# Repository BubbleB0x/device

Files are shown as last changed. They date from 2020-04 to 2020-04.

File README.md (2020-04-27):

# BUBBLEBOX DEVICE #

## INDICE ##
_________________________________________________________________________________________
1. Descrizione
2. Moduli e dispositivi utilizzati
3. inizializzazione
4. Directory Tree
5. Firmware Schede
6. Consumi, costi e caratteristiche
8. Connessione moduli(implementazione device)
9. Funzionamento

______________________________________________________________________________________________

## Descrizione ##
________________________________________________________________________________________________

Sistema di rilevamento di prossimità per prevenire e rilevare l’espansione del COVID-19 (e altre forme virali), attraverso l’uso di un device e di un App (non essenziale, ma che fornisce funzionalità aggiuntive) smartphone e web. Oltre all’analisi dei dati, questo progetto, effettua soprattutto una raccolta puntuale, completa, precisa e organizzata, con dati pronti per essere analizzati, infatti, il device effettuerà un vero proprio Edge Computing, in modo da gestire lui stesso i dati e presentarli, attraverso più canali comunicativi (Bluetooth smartphone o WiFi), al sistema server. Il nome BubbleBox proviene proprio dall’idea di una bolla virtuale attorno ad ogni individuo che, se violata, da quella di un altro, ottiene ID di quest’ultimo (in modo sicuro e anonimo) e invia la segnalazione ad un server online, dopo essere stato elaborato, per analisi e verifiche future. Se un individuo dovesse essere positivo al COVID-19 allora verranno allertate e controllate tutte le persone con cui è entrato in contatto senza ambiguità alcuna. A differenza di alcuni sistemi di tracciamento già presenti, il nostro fornisce un servizio funzionante in ogni luogo e offline, perché la raccolta avviene prima in locale poi, quando disponibile, viene inoltrata online.

---> [REPORT](https://github.com/BubbleB0x/device/blob/master/doc/report/Relazione_Bubblebox(RignanesePolenta).pdf)

----------------------------------------------------------------------------------------------------

## Moduli e dispositivi utilizzati (singolo device) ##
___________________________________________________________________________________________________

* ESP32
* RF-NANO
* Display LED
* Modulo RTC
* Modulo scheda SD

-----------------------------------------------------------------------------------------------------

## Inizializzazione ##

____________________________________________________________________________________________________

* Installazione [IDE Arduino](https://www.arduino.cc/en/Main/Software)
* Installazione CORE ESP32:
	- Arduino IDE > `File` > `Impostazioni` > `Schede` > URL Schede > `https://dl.espressif.com/dl/package_esp32_index.json`
	- Arduino IDE > `Strumenti` > `Scheda` > `ESP32 Dev Model`
	- Arduino IDE > `Strumenti` > `Partition Scheme `> `NO OTA (2MB APP/2MB SPIFFS)`
* Installazione Librerie:
	* Installazione [librerie ESP32](https://github.com/espressif/arduino-esp32)
		- Il link contiene tantissime librery per il device ESP32, tuttavia, nella repo è presente solamente la libvreria utile che viene utilizzata (per facilitare l'inizializzazione)
		- Arduino IDE > Sketch > #Include libreria > Aggiungi libreria da file .ZIP
	* Installazione [librerie NRF24L01](https://github.com/maniacbug/RF24)
		- Arduino IDE > Sketch > #Include libreria > Aggiungi libreria da file .ZIP
	
	----------> TUTTE LE LIBRERIE CHE SERVONO SONO INSERITE NELLA DIRECTORY `/Library`
	
* Possibili problematiche: 
	- è possibile che quando si connette l'ESP32 alla porta USB del PC non venga letta
	- aprire `Gestione Dispoitivi`
	- vedere se tra i device presenti c'è qualche problema o warning
	- andare sul problema e cliccare col tasto destro > `Aggiorna Driver`
	- il problema dovrebbe essere rsolto riavviando la IDE di Arduino

_____________________________________________________________________________________________________
	
## Directory Tree ##
_____________________________________________________________________________________________________

* *img*: Logo e altre immagini
* *firmware*:
	* *ESP32*:
		* *Device_SempreAttivi*: Device con ESP32 sempre in funzione (grande spreco di batteria)
		* *Device_Sleep&Wake*: Device con ESP32 in DeepSleep (grande risparmio di batteria)
	* *RFNANO*: Modulo RFNano con NRF24L01 per scandagliare l'area alla ricerca dei device vicini (consuma meno del modulo ESP32 e viene usato solo per scandagliare l'area) funziona a supporto dell'ESP32
* *doc* : 
	* *business_plan*
	* *report*
	* *altri documenti*
* *scheme*: Schemi sul funzionamento del device
* *Library*: Contiene tutte le librerie che servono ai componenti per poter funzionare
* *circuits*

_______________________________________________________________________________________________________

## Firmware Schede ##
________________________________________________________________________________________________________
* Clonare la repo
	- `git clone https://orteip94@bitbucket.org/bbteam_/bubblebox-device.git`
* Installare gli sketch sulle schede:
	- RFNANO:
		- Aprire Arduino IDE
		- Inserire la scheda RFNAno
		- Arduino IDE > Strumenti > Scheda > Arduino Nano > `Processore:ATMega328P`
		- Selezionare Porta
		- Installare sketch contenuto nella directory `Sketch Device/RFNano`
	- ESP32:
		- Aprire Arduino IDE
		- Inserire la scheda ESP32
		- Arduino IDE > Strumenti > Scheda > `ESP32 Dev Model`
		- Arduino IDE > Strumenti > Partition Scheme > `NO OTA (2MB APP/2MB SPIFFS)`
		- Selezionare Porta
		- Installare sketch contenuto nella directory `firmware/ESP32/Device_Sleep&Wake`
	
_______________________________________________________________________________________________________

## Consumi costi e caratteristiche componenti ##
________________________________________________________________________________________________________

| *Componente* | *Consumo Wake* |  *Consumo DeepSleep*  | *Prezzo* | *Caratteristiche* |
| ---|---|---|---|---|
| ESP32 | 50mA |  0,05 mA | 9€ | Wi-Fi & BLE |
| RF-NANO  | 19mA | 0,05 mA | 8€ | Radio Wave |
|Display OLED| 30mA | 0,9 mA | 8€ | Display 0.96" |
| Lettore SD |  30mA | 5 mA | 5€ | Data Storage  |
| Modulo RTC |0,8mA | 0,08 mA | 6€ | Orologio e data |
|  | *Totale*  |  *Totale* |  *Totale*  |  |
| - | 130 mA |  6,08 mA | 36€ | - |

## Connessioni Dispositivi(Implementazione Device) ##
_________________________________________________________________________________________________________

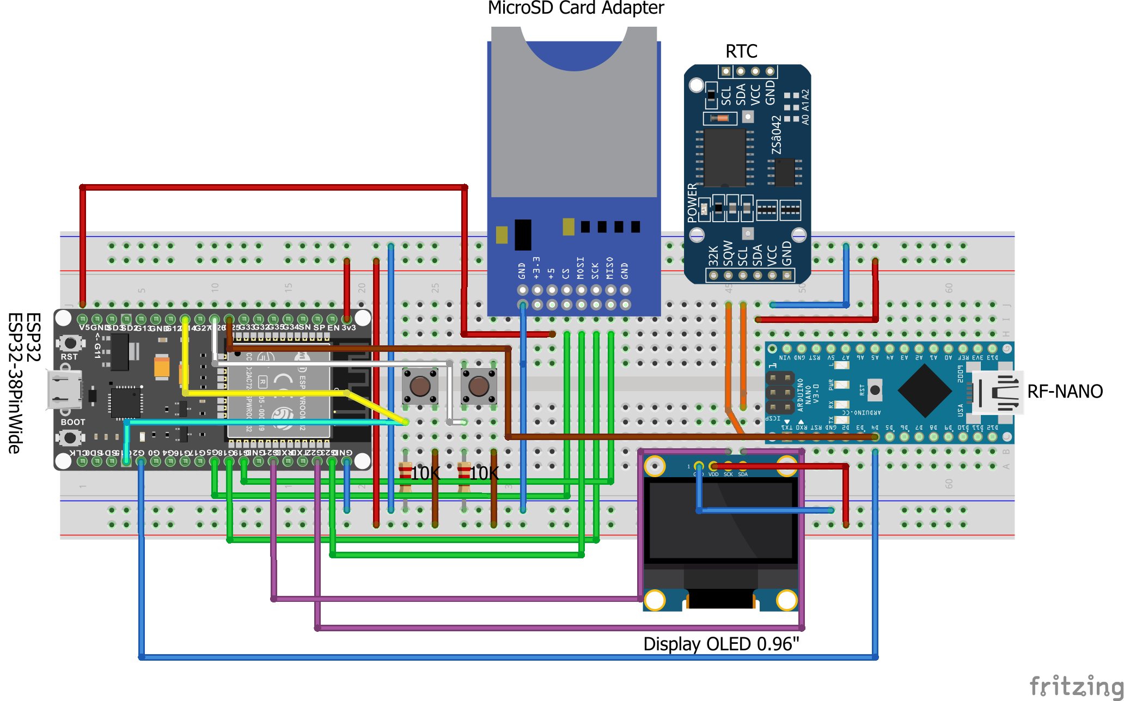
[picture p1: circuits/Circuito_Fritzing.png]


| *ESP32* | *RFNANO* |  *RTC*  | *DISPLAY* | *SD CARD* | *Bottone 1* | *Bottone 2*|
| ---|---|---|---|---|---|---|
| GPIO 25 | D4 |  - | -  | - |  - |  -  |
| GPIO 21 | - |  SCL | SCL  | - |  -  |  - |
| GPIO 22 | - |  SDA  | SDA  | - | -  |  - |
| GPIO 19 | - |  - | -  | MISO  | -  |  - |
| GPIO 23 | - |  - | -  | MOSI | -  |  - |
| GPIO 18 | - |  - | -  | SCK | -  |  - |
| GPIO 5 | - |  - | -  | CS | -  |  - |
| GPIO 14 | - |  - | -  | - | OK(Cambio Display)  |  - |
| GPIO 26 | - |  - | -  | - | -  |  OK(Sel. Opzione Display) |
| GPIO 2 | D4(Wake)  |  - | -  | - | -  |  - |
| GPIO 15 | - |  - | -  | - | OK(WAKE)  |  - |
| 3V | - |  VCC  | VCC  | - | VCC  |  VCC |
| 5V | - |  -  | -  | VCC | -  |  - |
| GND | - |  GND  | GND  | GND | GND  |  GND |

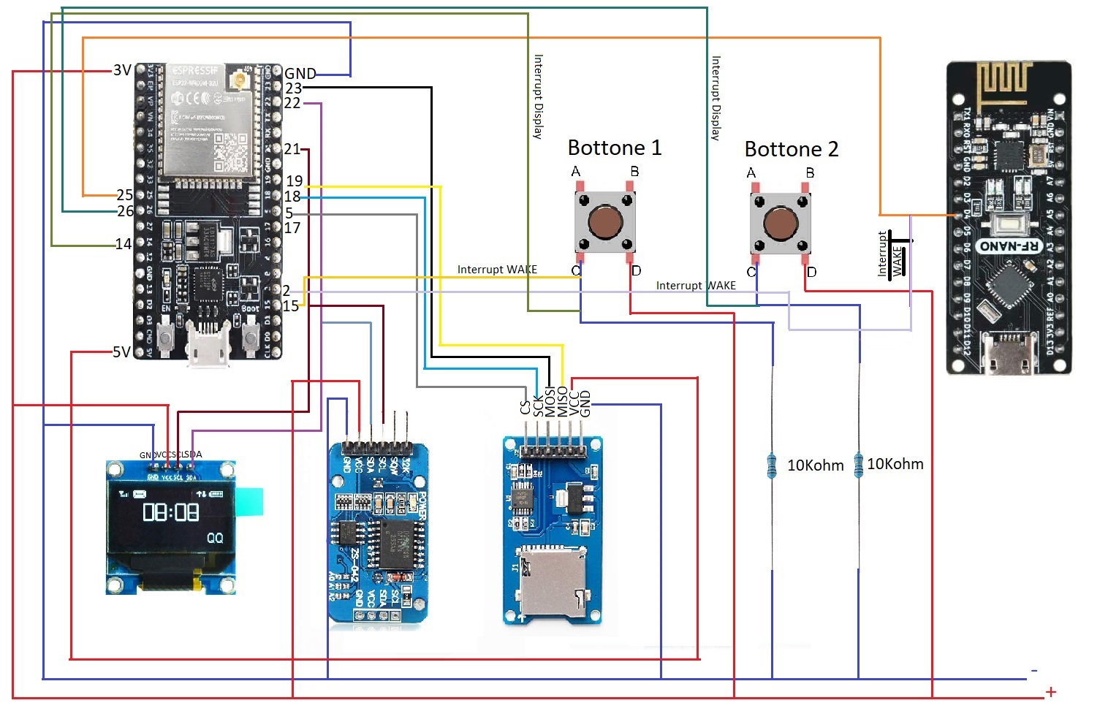
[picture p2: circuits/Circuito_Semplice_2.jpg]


## Funzionamento ##

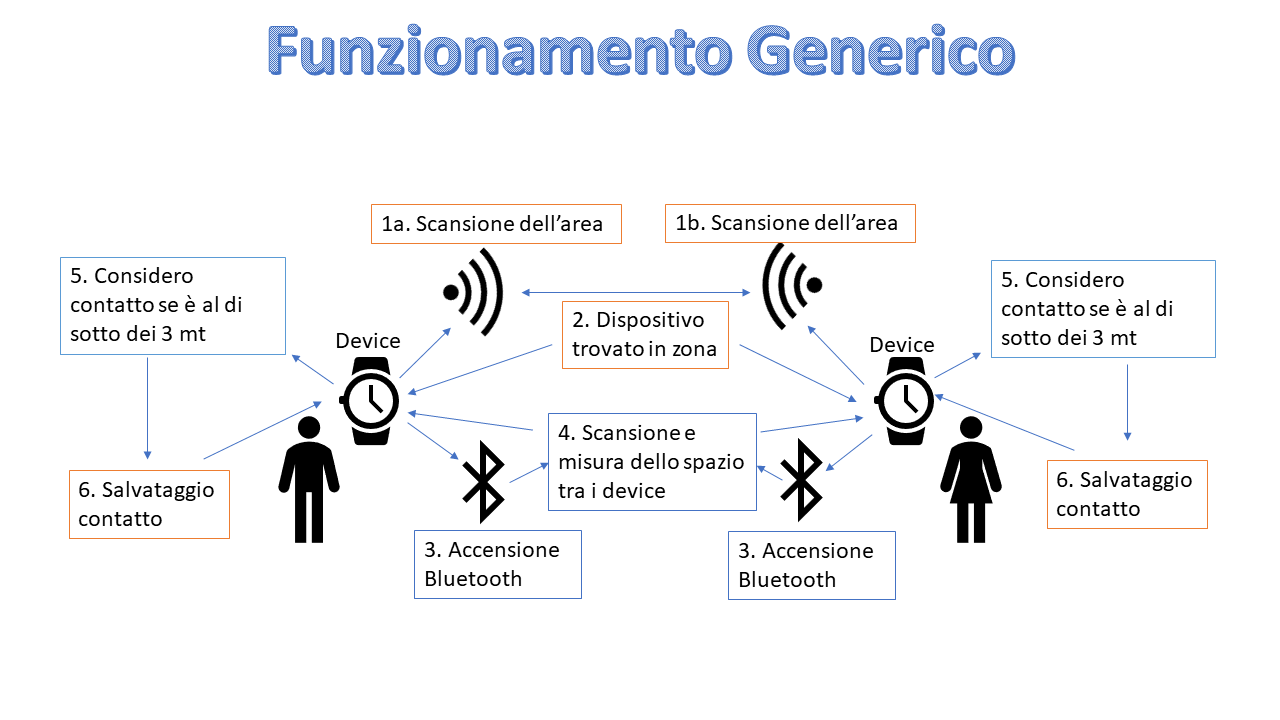
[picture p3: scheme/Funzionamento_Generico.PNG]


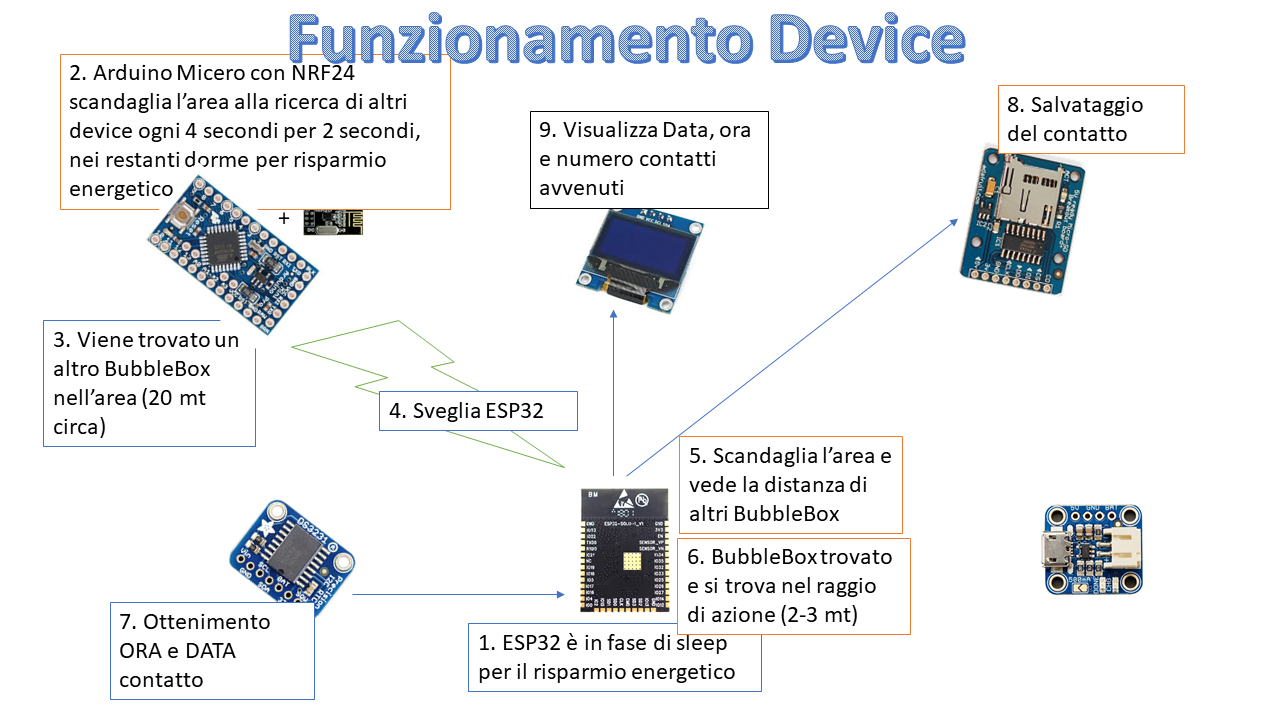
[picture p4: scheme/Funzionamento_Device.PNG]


### Flow-Chart ###

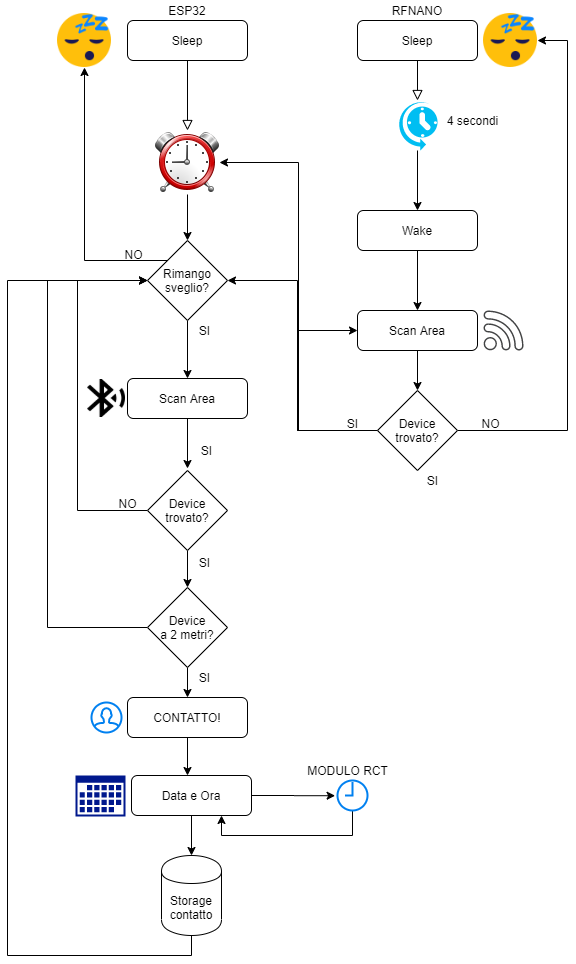
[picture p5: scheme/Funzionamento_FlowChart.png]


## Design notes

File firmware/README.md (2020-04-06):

## Moduli ##
___________________________________________________________________________________________________________-

[ESP32 pin](https://i0.wp.com/microcontrollerslab.com/wp-content/uploads/2019/02/ESP32-pinout-mapping.png?ssl=1)

[RFNano pin](https://images-na.ssl-images-amazon.com/images/I/717LoBu3zFL._AC_SX679_.jpg)

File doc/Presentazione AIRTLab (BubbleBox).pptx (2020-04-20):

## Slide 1

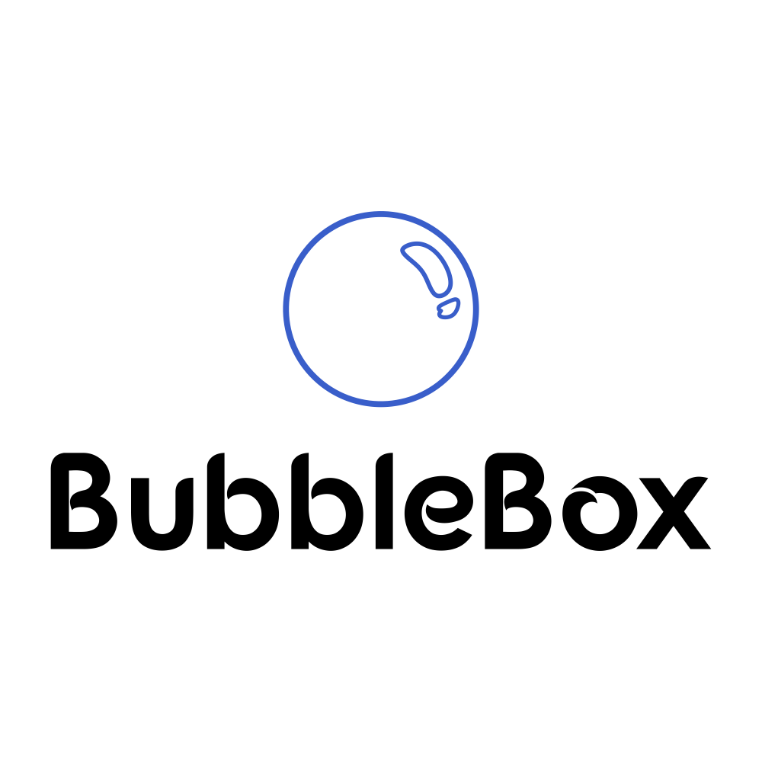
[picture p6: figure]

Powered
By

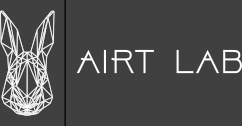
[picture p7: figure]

Prof. Aldo Franco Dragoni
UNIVPM

Pietro Rignanese & Andrea Polenta

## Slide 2

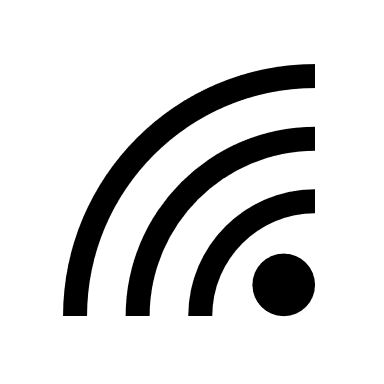
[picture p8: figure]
Wireless

Cos’è una BubbleBox?

- Un’area protettiva virtuale attorno ad ogni individuo
- Sistema di rilevamento di prossimità per prevenire e rilevare l’espansione del COVID-19

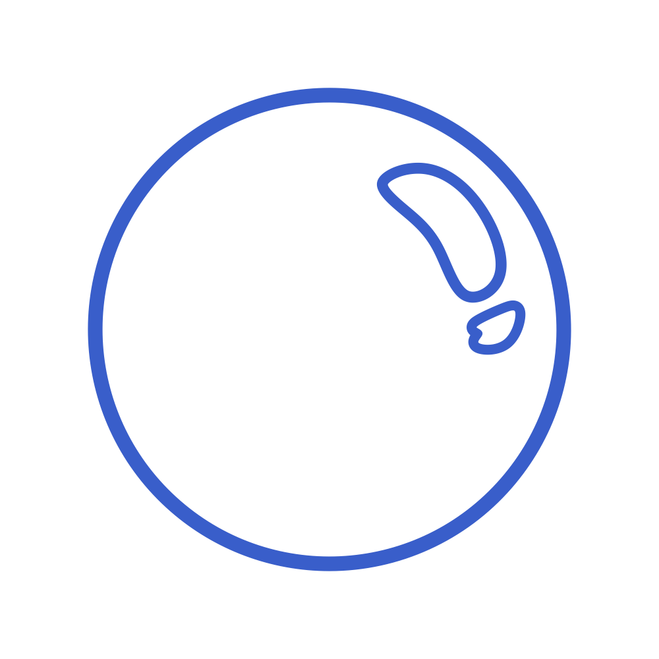
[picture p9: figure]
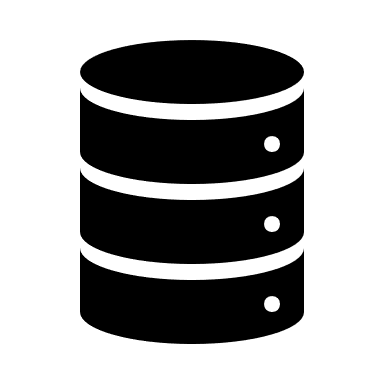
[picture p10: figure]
Database

A cosa serve una BubbleBox?

- Segnalazione e raccolta puntuale di ogni possibile contatto tra persone
- A far rispettare la distanza di sicurezza

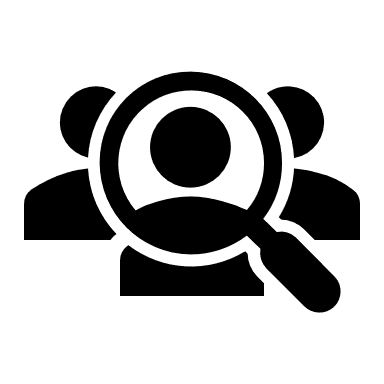
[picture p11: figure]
Pubblico target

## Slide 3

Come funziona una
BubbleBox?

Quando le due bolle entrano in contatto tra loro, il sistema si abilita e avviene uno scambio di identificativi con successivo inoltro su CLOUD.

Consideriamo due individui:
Fintanto che sono distanti, tra loro, più del diametro della «Bolla», non accade nulla.

Scambio Dati

Cloud

BubbleBox

Cloud

Invio Dati

Invio Dati

BubbleBox

10 mt

Violazione Area Privata

2-3 mt

2-3 mt

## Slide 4

Da cosa viene generata una BubbleBox?

- Da un device:
  - ESP32
  - Moduli
Utilizzando un dispositivo
A onde radio a corto raggio

- Smartphone
Utilizzando il Bluetooth

oppure

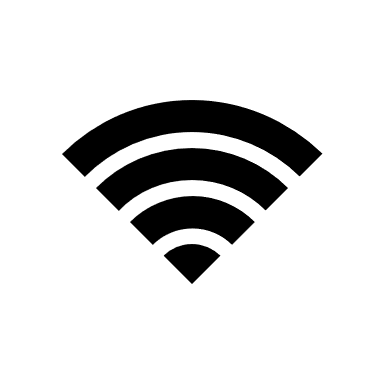
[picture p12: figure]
Wi-Fi
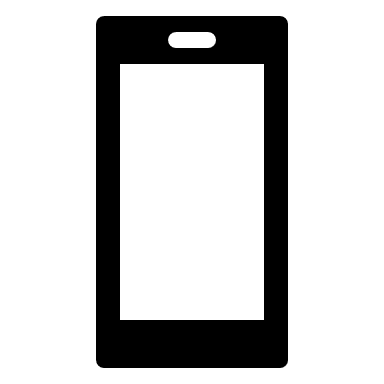
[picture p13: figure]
Smartphone
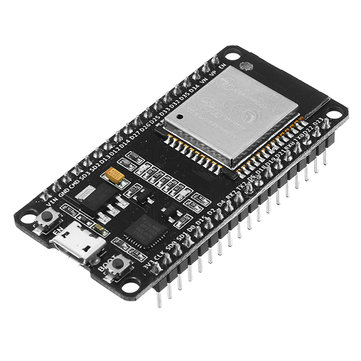
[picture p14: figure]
esp32 scheda di sviluppo wifi + bluetooth ultra-basso consumo ...

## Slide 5

Device nei particolari...

Scandaglia l’area alla ricerca di altri device, se ne trova, sveglua ESP32 (Risparmio energetico)

Elabora i dati ricevuti

Memoria di massa del device

Manda dati al CLOUD

Arduino Micro con NRF24

RTC DS3231

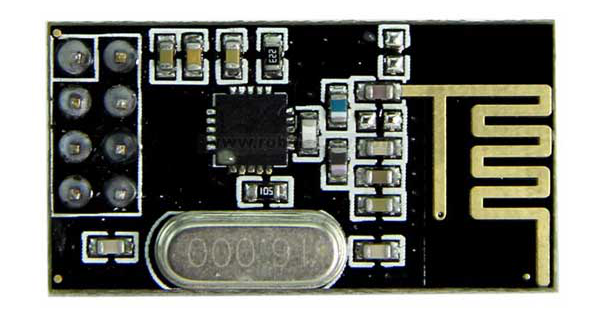
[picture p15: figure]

MicroSD Adapter

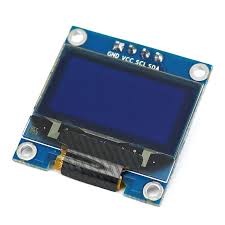
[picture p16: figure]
NEW 0.96 inch OLED Display Module IIC interface 0.96" 128X64 oled ...

ESP-32 Chip

Recharge Battery

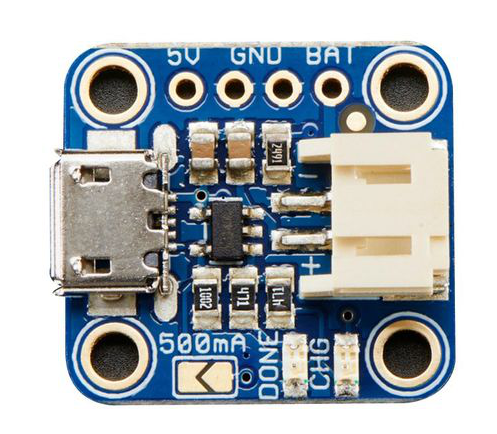
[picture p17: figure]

Si connette ad uno smartphone o alla WIFI

Display 0.96

Device

Manda segnali Radio e li intercetta tramite BLE (Bluetooth Low Energy)

Ricarica la batteria di alimentazione

Mantiene il conteggio della data e ora

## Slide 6

Cosa succede una volta che
i dati sono in CLOUD?

- Sarà possibile accedere, online, ad un’area riservata dove:
  - Ogni persona può osservare tutti i contatti avvenuti giornalieralmente e nell’arco di 15-20 giorni
    - La privacy delle persone resta tutelata perché ogni individuo saprà solamente che ha avuto un contatto con un’altra persona (con relativo luogo del contatto) e non di chi si tratta
    - I dati saranno pienamente disponibili per le autorità e la sanità per controllare ogni singola persona

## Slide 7

Cosa succede una volta che
i dati sono in CLOUD?

- Una persona che avverte dei malori o pensa di essere infetta (COVID-19 o altre emergenze future), potrà mandare una segnalazione direttamente dall’area riservata che verrà raccolta direttamente dal sistema e verranno avvertite le autorità per effettuare i dovuti controlli
  - Tutte le persone che hanno incontrato il «possibile infetto» verranno avvertite e dovranno restare in isolamento casalingo fino a ulteriori disposizioni
- Se le autorità sanitarie hanno constatato che il paziente è positivo, allora verranno controllate anche tutte le persone che hanno avuto un contatto con quest’ultima nell’arco dei 15 giorni
  - Tutte le persone che hanno incontrato l’infetto verranno avvertite e saranno soggette a tampone e isolamento, come da procedura.

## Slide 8

Come potrebbero essere usati
I dati raccolti?

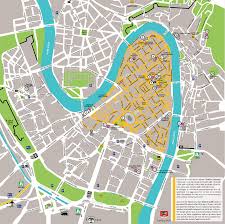
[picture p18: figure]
Risultato immagini per mappa

1. Sapere subito
Quali sono le persone
Entrate in contatto con
Un infetto in modo
Da intervenire tempestivamente

2) Analisi dei dati
Per verificare
La diffusione e
Il tracciamento del virus

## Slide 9

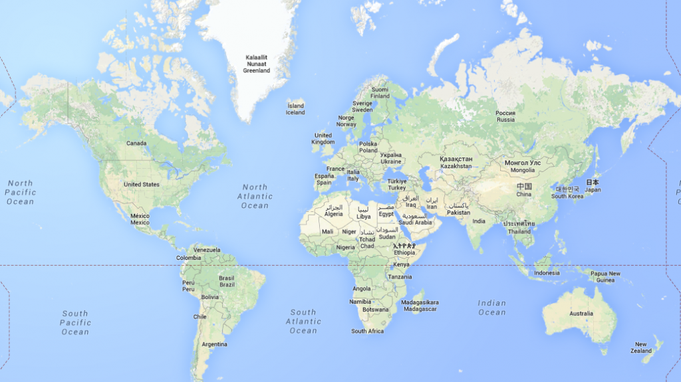
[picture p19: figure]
Risultato immagini per mappa
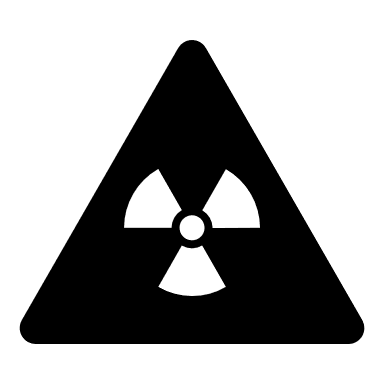
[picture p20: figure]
Simbolo radioattività

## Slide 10

3) Sapere su quali persone
Agire per effettuare dei
«Tamponi» campione, in modo
Da controllare un numero piccolo
Di persone, ma in modo più efficace

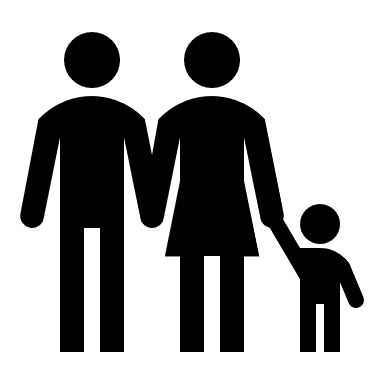
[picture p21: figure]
Famiglia con figlio
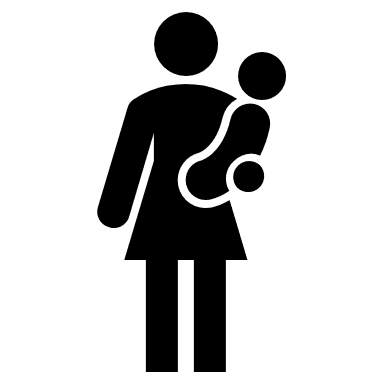
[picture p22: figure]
Donna con neonato
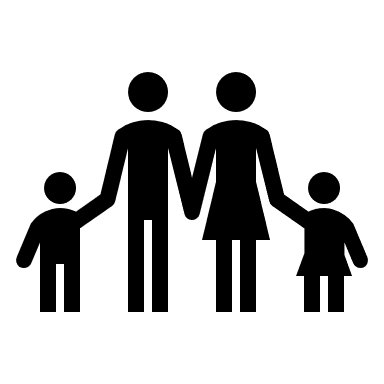
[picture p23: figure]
Famiglia con due figli
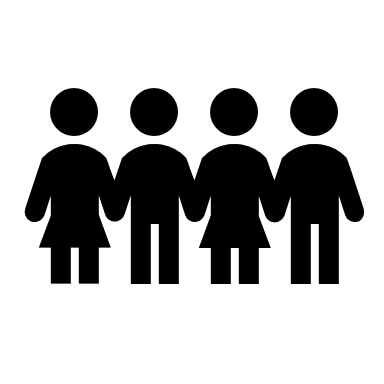
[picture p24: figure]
Bambini
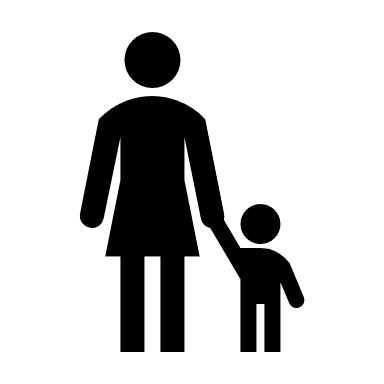
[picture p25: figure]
Donna con bambino

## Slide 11

4) Controllare, in modo veloce,
l’identità delle persone e il perché
Sono in giro anche se vice la regola
«RESTA A CASA»
(controllo anche con droni aerei)

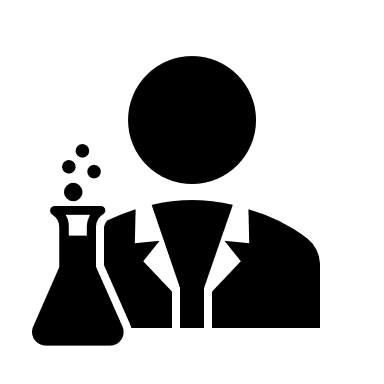
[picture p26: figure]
Scienziato
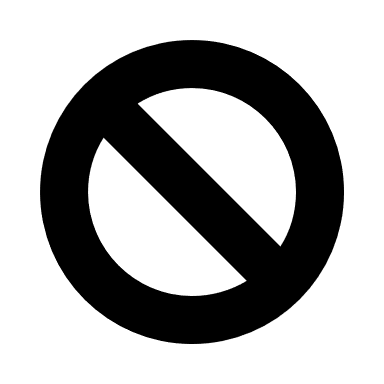
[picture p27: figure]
Segnale di divieto

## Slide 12

5) Controllo degli accessi
In determinati luoghi
Alle sole persone addette,
o ad un pubblico ridotto
(anche di numero)

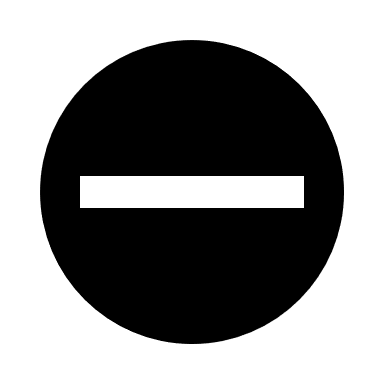
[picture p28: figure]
Vietato

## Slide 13

In quali ambiti può essere utilizzato
Il nostro device?

- Sanitario:
  - Tracciamento virus e patologie
  - Monitoraggio
  - Rispetto norme di sicurezza
- Sociale e investigativo:
  - Rintracciare persone incontrate
  - Tracciare profilo persona
- Tecnologico:
  - Gestire accesso ai soli addetti

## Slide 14

Pro e Contro
Hardware

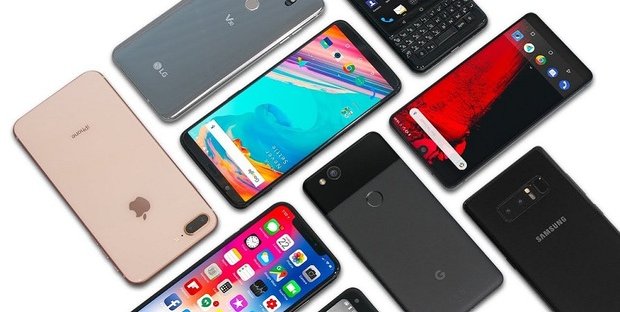
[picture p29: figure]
Risultato immagini per smartphone

- Smartphone:
  - Pro:
    - Tutti ne possiedono uno (o quasi…)
    - Tecnologia Bluetooth molto usata
    - Distribuzione dell’APP rapida
    - Realizzazione
  - Contro:
    - Implementazione non agevole
    - Sistemi operativi IOS poco adatti allo scopo
    - Batteria non dedicata
    - Il sistema Bluetooth consuma molta energia usato per molto tempo

- Device:
  - Pro:
    - Leggero e maneggevole
      - Bracciale
      - Collana
      - Cover per smartphone
      - …
    - Poco costoso
    - Implementazione agevole
    - Batteria dedicata
    - Bassi consumi
  - Contro:
    - Tempi per la realizzazione e la distribuzione

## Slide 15

Conclusione

La nostra idea non è solamente un’analisi dei dati, ma soprattutto una raccolta puntuale, completa e organizzata, con dati pronti per essere analizzati
Nonostante le grosse intemperie incontrate, in entrambe le soluzioni proposte, si stanno cercando di realizzare entrambi i sistemi.
A nostro avviso la realizzazione di un device, una volta distribuito, può coprire tutta la popolazione, mentre, per smartphone, abbiamo dei problemi di distribuzione per alcune tipologie di sistemi operativi, versioni e utenza (alcune persone potrebbero non averne uno).
Secondo la nostra esperienza e ricerca, il device rimane la scelta migliore, anche se dispendiosa (in termini di tempo e risorse) nella distribuzione.

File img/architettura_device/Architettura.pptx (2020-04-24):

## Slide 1

Download dal cloud

MQTT

Server
Database

MQTT

Wireless

SCAMBIO DATI

Router wireless

Bluetooth

Smartphone

WiFi

Bluetooth

Bluetooth

WiFi

Donna
Orologio
Uomo

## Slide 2

Server

Backend

3 Express.js features you need to know - JavaScript in Plain ...
Sincronizzazione cloud
Autenticazione di servizi REST con JWT [SPRING] - ItalianCoders
Stored Procedure in MYSQL WAMP - MIT India

Frontend

ionic-logo-portrait - Ionic AcademyIonic Academy

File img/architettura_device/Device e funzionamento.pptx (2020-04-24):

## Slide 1

Device Nei Particolari:

Arduino Micro


NRF24l01

Lettore MicroSD


+


Display OLED 0.96

NEW 0.96 inch OLED Display Module IIC interface 0.96" 128X64 oled ...

RTC DS3231


ESP32


Caricabatteria


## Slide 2

Funzionamento Device

2. Arduino Pro Micro con NRF24 scandaglia l’area alla ricerca di altri device ogni 4 secondi per 2 secondi, nei restanti dorme per risparmio energetico

9. Visualizza Data, ora e numero contatti avvenuti

8. Salvataggio del contatto

3. Viene trovato un altro BubbleBox nell’area (20 mt circa)

+

5. Scandaglia l’area e vede la distanza di altri BubbleBox

4. Sveglia ESP32

6. BubbleBox trovato e si trova nel raggio di azione (2-3 mt)

7. Ottenimento ORA e DATA contatto

1. ESP32 è in fase di sleep per il risparmio energetico

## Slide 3

Funzionamento Generico

1a. Scansione dell’area

1b. Scansione dell’area

Wireless

5. Considero contatto se è al di sotto dei 3 mt

2. Dispositivo
trovato in zona

4. Scansione e misura dello spazio tra i device

5. Considero contatto se è al di sotto dei 3 mt

Device

Orologio

Device

Uomo
Donna

6. Salvataggio contatto

Bluetooth

3. Accensione Bluetooth

3. Accensione Bluetooth

6. Salvataggio contatto

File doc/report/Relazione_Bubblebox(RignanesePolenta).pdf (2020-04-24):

# RELAZIONE PROGETTO BUBBLEBOX

Relazione e manuale di utilizzo device e app BubbleBox

### SUNTO

Sistema di rilevamento di prossimità per prevenire e rilevare l’espansione del COVID-19 (e altre forme virali), attraverso l’uso di un device e di un App (non essenziale, ma che fornisce funzionalità aggiuntive) smartphone e web. Oltre all’analisi dei dati, questo progetto, effettua soprattutto una raccolta puntuale, completa, precisa e organizzata, con dati pronti per essere analizzati, infatti, il device effettuerà un vero proprio Edge Computing, in modo da gestire lui stesso i dati e presentarli, attraverso più canali comunicativi (Bluetooth smartphone o WiFi), al sistema server. Il nome BubbleBox proviene proprio dall’idea di una bolla virtuale attorno ad ogni individuo che, se violata, da quella di un altro, ottiene ID di quest’ultimo (in modo sicuro e anonimo) e invia la segnalazione ad un server online, dopo essere stato elaborato, per analisi e verifiche future. Se un individuo dovesse essere positivo al COVID-19 allora verranno allertate e controllate tutte le persone con cui è entrato in contatto senza ambiguità alcuna. A differenza di alcuni sistemi di tracciamento già presenti, il nostro fornisce un servizio funzionante in ogni luogo e offline, perché la raccolta avviene prima in locale poi, quando disponibile, viene inoltrata online.

### Pietro Rignanese e Andrea Polenta

Sistemi Operativi Distribuiti Tempo Reale

## Sommario

## INTRODUZIONE

Cos’è BubbleBox e perché si è voluto dare questo nome a questo progetto universitario. Le domande che ci si pone sono tante, anche come affronteremo l’emergenza “Coronavirus” o altre future epidemie. Questa proposta, appoggiataci dal professor Aldo Franco Dragoni, dell’università politecnica delle marche e dal suo laboratorio AIRTLab, nasce dall’idea di poter gestire, controllare la diffusione di una qualsiasi forma di virus e patologia, raccogliendo i dati, tra tutti gli utenti, in modo puntuale ed efficiente. L’intera elaborazione e raccolta dei dati avviene in locale direttamente sul device (che ha l’aspetto di un normalissimo orologio da polso), in modo da non sovraccaricare troppo il sistema server. I dati da mandare al server viaggiano attraverso canali comunicativi semplici da utilizzare perché utilizzati costantemente ogni giorno (da chiunque o dalla stragrande maggioranza delle persone), tra cui la connessione allo smartphone, tramite Bluetooth, e la connessione ad una rete WiFi attraverso il bottone WPS, qualora fosse disponibile, o la normalissima connessione con SSID e Password, inoltre i dati viaggiano su protocolli di comunicazione leggeri di tipo publish-subscribe chiamato MQTT (Message Queue Telemetry Transport) che ha un bassissimo impatto e richiede pochissima banda.

Oggi, Aprile 2020, siamo in piena emergenza COVID-19, ci sono ancora tantissimi casi di contagi, anche se il numero dei malati guariti supera quello dei morti, le vite che sono state portate via superano i 20 mila e questo numero continua a salire, la paura rimane e le persone sono costrette a rimanere in casa e adottare misure molto restrittive e precauzionali. Cosa succederà quando dovremo cominciare a tornare alle nostre normali vite e frequentare di nuovo luoghi affollati? Il nostro progetto è mirato a garantire un’ulteriore misura di sicurezza, oltre a quelle da rispettare, ma che riesce a gestire l’intera emergenza in modo poco invasivo e restrittivo.

Questa idea di progetto nasce nel Febbraio 2020, quando, a due studenti (Pietro Rignanese e Andrea Polenta), del corso magistrale di “Ingegneria informatica e dell’automazione” dell’UNIVPM, viene in mente che si potrebbe realizzare un device apposito per poter monitorare il virus o qualsiasi forma virale (il device è molto versatile e potrebbe essere utilizzato in moltissimi ambiti, da quello sanitario, aziendale, per monitorare gli accessi in are o limitare il numero di accessi ecc…). Il nome BubbleBox sta proprio a immaginare una bolla protettiva attorno ad ogni persona, una bolla che “SCOPPIA” quando la sua sfera personale e privata viene a contatto con quella di un’altra persona.

Attraverso degli studi, e per le normative di legge in vigore dal Marzo 2020, le persone devono distanziarsi di almeno un metro uno dall’altro. Questa normativa non sempre viene seguita alla lettera e risulta difficile in situazioni particolari, infatti, ricordare tutte le persone che si sono incontrate in tutti i posti che si sono visitati negli ultimi 15 giorni risulta essere complicato e non tutti ricordano ogni singola persona incontrata, anche perché si possono frequentare posti in cui ci sono persone che non si conoscono (bar, farmacie, pizzerie, supermercati, ecc…). Il BubbleBox serve proprio a questo: catturare ogni singolo contatto avvenuto tra due o più individui, in modo che, quando uno di questi individui risulta essere infetto, si potrà risalire, in modo specifico e puntuale, a quelli che sono stati i suoi contatti negli ultimi 15-20 giorni e agire prontamente per isolare chi serve ed evitare la diffusione non controllata del virus. Le persone avranno i propri dati completamente oscurati agli altri e protetti, infatti si potrà conoscere solamente il numero di persone incontrate giornalmente, o negli ultimi 15 giorni, e non di chi si tratta proprio per non infrangere la privacy di ogni singolo individuo. La privacy è importante è il nostro progetto prevede di tutelarla attraverso ogni forma di gestione e controllo possibile. I dati saranno disponibili, qualora servissero, solamente alla sanità, o chi gestirà l’emergenza, per poter eseguire le varie prevenzioni, controlli e tamponi.

Oltre all’analisi dei dati, questo progetto, effettua soprattutto una raccolta puntuale, completa e organizzata, con dati pronti per essere analizzati (avere già dei dati pronti e privi di rumore, garantisce un’analisi più accurata, semplice e precisa). Se un individuo dovesse essere positivo al COVID-19 (o altri virus, in futuro) allora verranno allertate e controllate tutte le persone con cui è entrato in contatto senza ambiguità alcuna. A differenza di alcuni sistemi di tracciamento già presenti, il nostro fornisce un servizio funzionante in ogni luogo e offline, perché la raccolta avviene prima in locale poi, quando disponibile, viene inoltrata online attraverso varie metodologie.

Il progetto non è limitato solo all’utilizzo del device, ma ci sarà a disposizione anche una App apposita (non essenziale ma che fornisce delle funzionalità in più) per smartphone o web per poter accedere ai propri dati e visualizzare le funzionalità da eseguire, come il numero di persone con cui si è entrati in contatto e la segnalazione delle patologie. Questi dati saranno utilizzati quando si verifica un contagio, in modo che sarà possibile risalire, andando a ritroso, alla persona malata che ha cominciato a diffondere il virus.

Si vive in tempi difficili ed è per questo che dobbiamo cambiare i nostri modi di comportarci e di analizzare i vari rischi. Questo device non fermerà l’avanzare del virus in questione, ma potrebbe dare una grossa mano a tante persone, specialmente medici e sanità, in modo da poter monitorare e gestire le varie emergenze e tenere sott’occhio l’avanzamento del virus e lo stato di salute delle persone a rischio.

## UTILIZZI


Gli utilizzi del device sono molteplici, oltre a raccogliere i dati in modo puntuale e preciso, questi dati possono essere utilizzati per:

- Sapere subito quali sono le persone entrate in contatto con un infetto o un probabile infetto in modo da intervenire prontamente
- Analisi dei dati per verificare la diffusione e il tracciamento del virus
- Sapere su quali persone agire per effettuare dei “Tamponi campione” in modo da controllare un numero piccolo di persone ma in modo efficiente

- Controllare in modo veloce l’identità delle persone e il perché sono in giro anche se vice la regola “RESTA A CASA”
- Controllare gli accessi in determinati luoghi e far accedere solo persone addette, o far accedere un certo numero di persone

## ARCHITETTURA E FUNZIONAMENTO

### 1. ARCHITETTURA DEVICE

Il device è composto da tante piccole parti, ognuna delle quali svolge una particolare funzione:

- ESP32 WROOM 32:
- È un modulo che dispone sia di una componente WIFI (2.4 Ghz) e di una Bluetooth di tipo BLE (Bluetooth Low Energy)
- È molto piccolo e i suoi consumi si aggirano intorno ai 50 mAh quando è in funzione e 0.05 mAh quando è in fase di “sonno profondo” (deep sleep)
- Display OLED 0.96”:
- Display molto piccolo che serve a far visualizzare data, ora ed eventuali funzioni del device che è possibile utilizzare
- RTC DS3231:
- Modulo che tiene il conto della data e ora
- Arduino Micro + NRF24L01+:
- Questi due moduli vengono utilizzati per scandagliare l’area alla ricerca di un altri device BubbleBox e svegliare, quando ne viene trovato uno nei dintorni, l’ESP32, questo perché il suo consumo è sotto i 15 mAh

- Lettore MicroSD:
- Modulo per leggere una micro SD da utilizzare come memoria di massa
- Pila litio
- Caricabatterie

Questa struttura del device sarà la struttura finale. Ogni singola parte è grande come un’unghia o poco più, in modo che sarà possibile costruire un device leggero, facilmente trasportabile e che avrà le sembianze di un orologio da polso.

La struttura del device, per le varie prove e test, sarà leggermente diversa per motivi di comodità di sviluppo e praticità.

Ecco la struttura che andremo ad utilizzare per il prototipo ed effettuare i vari test:

- DevKit ESP32:
- Modulo con chip ESP32 WROOM 32 impiantato
- Facile da utilizzare e collegare con una breadboard e cavetti
- Display OLED 0.96”
- RTC DS3231

- RF-NANO:
- Modulo che racchiude Arduino Nano + NRF24L01
- Comodo da utilizzare e leggermente più grande del Micro
- Utilizzato per motivi di praticità
- Lettore SD Card
- Alimentazione USB

### 2. FUNZIONAMENTO DEVICE


Come si può vedere dall’immagine riportata, il funzionamento del device avviene attraverso 6 fasi principali:

1. Scansione dell’area:
a. Viene scansionata l’area alla ricerca di altri device per poter comunicare
b. La scansione avviene attraverso il modulo Micro + NRF24L01 (o nel caso semplice RFNANO) perché consuma pochissima energia rispetto all’ESP32 e copra un raggio di 20 metri.
2. Ritrovamento dispositivo:
a. La scansione ha trova in zona uno o più dispositivi BubbleBox di altre persone, questo significa che il dispositivo ESP32 deve entrare in funzione
3. Accensione Bluetooth:
a. Viene attivato il dispositivo bluetooth dell’ESP32
b. In questo momento il device mette a disposizione di tutti i dispositivi bluetooth le proprie informazioni (MAC, NOME e UUID)
4. Scansione e misura spazio tra device BoobleBox:
a. In questo momento l’ESP32 scansiona l’area e calcola la potenza dei segnali trovati per calcolare la distanza che gli separa (RSSI)
5. Contatto avvenuto:
a. Se i device sono al disotto della soglia da considerare (2 metri) scatta il contatto!
b. Considero il contatto
6. Salvataggio contatto:
a. Salvo, in locale, il contatto o i contatti avvenuti
7. Spegnimento device:
a. Spengo il device se non è presente alcun altro device BubbleBox nelle vicinanze per risparmiare energia.

Tutto il funzionamento può essere rappresentato nel dettaglio e su come le componenti interagiscono tra loro.


Come si può vedere dall’immagine, le fasi, per il funzionamento del device, sono molto più articolate e specifiche, in quanto, le componenti interagiscono fra loro per cambiarsi dati, salvarli e gestirli.

Le fasi sono le seguenti:

1. L’ESP32 è in fase di “sonno profondo” per risparmiare energia e non si sveglierà fino a che non sarà presente un altro device BubbleBox nelle vicinanze
2. Arduino Micro con NRF24L01 scandaglia l’area (in un raggio di 15-20 mt) alla ricerca di un altro device BubbleBox
a. La scansione avviene ogni 4 secondi e segue una fase di sonno profondo in quel lasso di tempo per poter risparmiare ancora energia
3. Viene ritrovato un altro device nelle vicinanze
4. Viene mandato un segnale di “WAKE” all’ESP32 per svegliarlo e tornare alle sue normali funzioni
5. L’ESP32 si sveglia, accende il suo Bluetooth e comincia a scandagliare l’area alla ricerca di un device BubbleBox
6. Se un device (BubbleBox) di un’altra persona viene trovato e si trova al disotto dei 2 metri, lo considera (si considera l’ID del device e non il nome o altri dati della persona, il completo anonimato è mantenuto per tutto l’iter)
7. Ottiene la data e l’ora dal modulo RTC
8. Salva il contatto sulla propria memoria
a. Il dato salvato avrà la seguente forma: DATA|ORA|MioID|IDContatto
b. Con MioID e IDContatto viene considerato il MAC address del bluetooth BLE ESP32

Tutte le fasi ed il funzionamento nello specifico è rappresentato dal seguente flowchart:


### 3. CIRCUITO DEVICE

Per definire il circuito, sono stati realizzati diversi schemi, in modo da rendere chiaro e preciso i vari collegamenti tra i moduli. Partiamo dal circuito specifico generale rappresentato dalla figura seguente:


Per tutte le prove, test e circuiti che verranno mostrati, saranno utilizzati i moduli di sviluppo (DEVKit) per semplicità di rappresentazione, costruzione circuito e funzionalità. Il tutta sarà poi replicato, una volta eseguiti i vari test, con i moduli più piccoli.

Il circuito che si sta osservando è molto specifico e si vedono i vari componenti nello specifico. Ogni singolo componente è collegato, principalmente, alla rete di alimentazione (3 Volt) e all’ESP32 che gestisce e orchestra l’intero sistema. Il display OLED sarà collegato ai due pin SDA e SCL dell’ESP32 che corrispondono, rispettivamente, a 22 e 21 (GPIO 22, GPIO 21), il modulo RTC, con i pin SDA e SCL, anch’esso ai pin 22 e 21 (questo non crea alcun problema all’ESP32, riuscendo a gestire due moduli anche se sono connessi agli stessi pin). Il modulo lettore di SD card, in questo caso, è alimentato a 5V, ma nel circuito finale sarà usato uno adatto con alimentazione a 3V, in modo da non creare problemi di alimentazione essendo che la pila al litio erogherà 3.7V. L’RFNANO sarà collegato all’ESP32 su due pin, uno per svegliarlo quando viene avvertito un altro device nelle vicinanze e l’altro per tenerlo sveglio. Sono presenti due bottoni per poter accendere il display e selezionare le opzioni che compaiono.

Di seguito il circuito installato sulla millefori:


Il seguente circuito è più semplice ed intuitivo del precedente e rappresenta una foto più dettagliata del prototipo con i collegamenti ben definiti. Infatti, come possiamo vedere, tale circuito è perfettamente paragonabile al circuito reale:


Nella foto, risulta molto più complesso capire i collegamenti, ma nello schema presedente i dettagli sono più definiti e sarà possibile ricreare il circuito sulla propria millefori (breadboard).

Per avere una linea guida sui collegamenti, di seguito è presente una tabella in cui è possibile vederli nel dettaglio:

ESP32 | RFNANO | RTC | DISPLAY | SD CARD | Bottone 1 | Bottone 2
GPIO 25 | D4
GPIO 21 | | SCL | SCL
GPIO 22 | | SDA | SDA
GPIO 19 | | | | MISO
GPIO 23 | | | | MOSI
GPIO 18 | | | | SCK
GPIO 5 | | | | CS
GPIO 14 | | | | | Cambio Display
GPIO 26 | | | | | | Sel. Opz. Display
GPIO 2 | D4 (WAKE)
GPIO 15 | | | | | WAKE
3V | | VCC | VCC | | VCC | VCC
5V | | | | VCC
GND | | GND | GND | GND | GND | GND

E di seguito un ulteriore schema di connessione con ulteriori dettagli per i collegamenti:

Il tutto dovrà poi essere riconducibile a questo schema:


Grazie alla grandezza di ogni singolo modulo, sarà possibile implementare l’intero sistema all’interno di un orologio da polso (o qualcosa di molto piccolo e facilmente trasportabile).

### 4. CONSUMI DEVICE

Di seguito sono riportati i consumi, in termini di milliampere, di ogni singolo componente del device:

Componente | Consumo Wake | Consumo DeepSleep
ESP32 | 50 mAh | 0.05 mAh
RFNANO | 19-30 mAh | 0.05 mAh
Display OLED | 20-35 mAh | 0.9 mAh
MicroSD | 40 mAh | 5 mAh
RTC DS3231 | 0.8 mAh | 0.08 mAh
| Totale | Totale
| ̴130-160 mAh | ̴7 mAh

Considerando una batteria al litio da 3.7V 500 mAh e considerando che i tempi di utilizzo del device e della media delle persone incontrate nell’arco di una giornata, otteniamo un consumo medio del device di circa 60 mAh (alternando le fasi di sonno profondo con quelle di accensione). Misurando i tempi di scarica della batteria otteniamo:

Durata Batteria =

Capacità batteria mAℎ
Corrente di carico mAℎ

=

500
60 = 8,33333 ≈ 8 ore e 20 minuti

Aumentando la capacità della batteria potremmo portare il tutto a funzionare per un’intera giornata.

Durata Batteria =

Capacità batteria mAℎ
Corrente di carico mAℎ

=

1000
60 = 16,66666 ≈ 16 ore e 40 minuti

Nel nostro caso, utilizzando i moduli adeguati al circuito finale otterremmo tali consumi:

Componente | Consumo Wake | Consumo DeepSleep
ESP32 | 50 mAh | 0.05 mAh
Arduino Micro | 5 mAh | 0.05 mAh
NRF24L01+ | 10-20 mAh | 0.04 mAh
Display OLED | 20-35 mAh | 0.9 mAh
MicroSD | 40 mAh | 5 mAh
RTC DS3231 | 0.8 mAh | 0.08 mAh
| Totale | Totale
| ̴120-150 mAh | ̴7 mAh

Un consumo energetico di 10 mAh più basso rispetto a quello in fase di sviluppo.

### 5. APP SMARTPHONE E WEB APP

Il software serve per effettuare varie operazioni:

- Operazioni Utente:
- Creare un accoppiamento con il proprio device → Individuo
- Inserire/Modificare le proprie credenziali
- Collegare device allo smartphone per scaricare i vari contatti avvenuti e inoltrarli al server
- Controllare tutti i contatti giornalieri avvenuti e quelli totali
- Mandare una segnalazione sul proprio stato di salute
- Permettere di gestire il device e le varie comunicazioni
- Gestire il trasferimento dei dati
- Opzioni Staff/Amministratori
- Analisi dei dati raccolti per comprendere quali sono le aree geografiche più colpite dal virus
- Raccolta delle segnalazioni al fine di effettuare tamponi mirati
- Recupero delle identità degli individui a contatto con dei positivi
- Invio repentino di informazioni a che è stato a contatto con positivi al fine di evitare l’espansione incontrollata del virus
- Sarà possibile, inoltre, effettuare data mining sui dati ottenuti al fine di rilevare eventuali correlazioni fra lo stato di salute degli individui e il presentarsi del virus

Tale software è suddiviso in 3 parti fondamentali:

- Frontend:
- Presenta la parte grafica da presentare all’utente
- Gestito dal framework chiamato IONIC per lo sviluppo di Progressive Web App
- Backend:
- Applicazione lato server adibita alla gestione dei dati provenienti dal frontend
- Implementata in Express Js, la gestione delle richieste è eseguita attraverso delle REST GET, POST, PUT, DELETE che a loro volta eseguiranno delle operazioni CRUD su un DB MySQL

- Database:
- Storage dei dati
- Gestito dall’RDBMS chiamato MySQL

5.1. Gestione dei dati
Come detto in precedenza per la gestione dei dati ci siamo affidati a MySql , l’RDBMS per eccellenza, conosciuto in tutto il mondo per le sue ottime prestazioni, versatilità e semplicità di utilizzo.

Il nostro obiettivo sarà dunque quello di creare una base di dati in grado di contenere

- l’insieme degli utenti che faranno uso del nostro servizio e di quelli lo gestiranno
- l’insieme dei devices BubbleBox appartenenti agli utenti che faranno uso del nostro servizio
- l’insieme dei contatti avvenuti nel tempo fra gli utenti che faranno uso del nostro servizio
- l’insieme delle segnalazioni effettuate dagli utenti che faranno uso del nostro servizio

L’utente potrà dunque registrarsi al nostro servizio indicando alcuni dati personali come nome, cognome, codice fiscale, data di nascita, indirizzo di residenza e sesso, inoltre verranno richiesti ulteriori informazioni significative come una mail e uno username per poter effettuare un accesso più agevole al servizio. Fatto ciò l’identità di un utente dovrà essere controllata tramite appositi strumenti, dunque verrà inviata una mail di conferma e il servizio sarà disponibile. Verranno associate all’utente ulteriori informazioni come il ruolo all’interno del servizio (user, staff, admin) e uno stato di salute che indicherà dunque le condizioni dell’utente (“sano”, “con sintomi”, “in quarantena”, “positivo”, “positivo asintomatico”).

Una volta effettuata la registrazione, l’utente dovrà registrare il proprio device identificato nel sistema con un indirizzo mac. Parlando dunque dei devices, questi verranno rilasciati con un indirizzo mac (di natura univoco) prestabilito.

Dopodiché una volta associato il dispositivo l’utente lo potrà indossare per rilevare i contatti che avvengo fra di esso e gli altri individui che ne indossano uno. Ogni contatto comporta la ricezione del MAC relativo al dispositivo di un altro utente e la memorizzazione in locale di una stringa con il seguente format: “MAC_del_mio_device|MAC_del_device_incontrato|timestamp” che verrà successivamente inviata su un cloud online.

Quando un utente facente parte del servizio accusa i sintomi del virus, dovrà riportarli nell’apposita sezione adibita alle segnalazioni, i dati raccolti saranno dunque utili per comprendere le condizioni del segnalatore che sarà verrà prontamente soccorso. I dati da inserire saranno relativi ai sintomi tipici del virus in considerazioni. Effettuata la segnalazione lo stato dell’utente passerà da “sano” a “con sintomi”, da questo punto in poi solo le autorità sanitarie potranno cambiare lo stato di salute dell’individuo; ad esempio, nel caso del COVID, poco dopo fatta la segnalazione, l’utente sarà soggetto a tampone e una volta conosciuto l’esito potrà passare o meno in stato di “positivo”. Quando un individuo passa allo stato di “positivo”, le autorità potranno entrare a conoscenza delle persone con le quali questo è stato a contatto definendo una finestra temporale congrua con i tempi di vita del virus. Le persone a contatto con quest’ultimo passeranno dunque in stato di “in quarantena” e verranno successivamente controllate dalle autorità sanitarie.

5.1.1. Schema ER
Dunque, una volta centrato l’obiettivo, identifichiamo quattro entità correlate tra di loro:
- Users, cioè l’insieme degli utenti che usufruiranno del servizio e quelli che lo gestiranno.
- Devices, cioè l’insieme di tutti i devices bubblebox.
- Blasts, cioè l’insieme di tutti i contatti che sono avvenuti nel tempo fra le istanze di Users
- Symptoms, cioè l’insieme di tutte le segnalazioni eseguite dagli utenti che hanno riscontrato dei sintomi tipici del Virus che si sta cercando di debellare (prenderemo per ora in esempio quelli relativi al COVID-19.

E possiamo inoltre individuare quattro relazioni che insorgono fra di esse:

- Una relazione tra Users e Devices, in quanto ogni utente avrà associato ad esso un device
- Una relazione tra Symptoms e Users in quanto ogni utente può eseguire delle segnalazioni
- Due relazioni tra Blasts e Devices in quanto nella prima verranno riportati i devices entrati in contatto e dunque ci saranno due attributi legati a Devices.

Ecco lo schema ER risultante:


Dallo schema ER estrapoliamo dunque il relativo schema relazionale:

### 6. FUNZIONAMENTO DEVICE + APP


Come è possibile vedere dall’immagine, il funzionamento del device e da accorpare a quello dell’app smartphone o attraverso l’ausilio di altri mezzi di comunicazione, tra cui un Access Point (AP).

- Il device una volta raccolte le informazioni dei contatti le elabora ed effettua uno storage in locale:
- Si dispongono di diversi file, uno per ogni giorno, in modo da avere un catalogo bene fornito e specifico di tutti i contatti avvenuti:
- ESEMPIO:
- Contact_2020_04_11
- Contact_2020_04_12
- …
- Contact_2020_05_30
- …
- Una volta raccolte le informazioni, queste possono essere mandate, quando si vuole, al server attraverso due canali di comunicazione che è possibile scegliere:
- Bluetooth smartphone:
- Collegandosi allo smartphone e passando in automatico tutti i contatti per poi essere inoltrati al server e messi in un DB
- WiFi:
- Collegandosi ad un AP attraverso un normalissimo protocollo WIFI o WPS:
- WPS: collegarsi all’AP schiacciando il bottone presente sul router domestico e attendere la connessione
- WIFI SSID PASS: collegandosi in modo tradizionale al WiFi di casa inserendo le credenziali di accesso che verranno passate quando ci si collega allo smartphone (visto che il device non ha un tastierino con cui comporre messaggi)

### 7. FUNZIONAMENTO APP


Il funzionamento della App è un po' più articolato del resto, perché ogni richiesta che passa al server deve essere prima inoltrata al Backend, verificata e poi eseguita. Questo meccanismo di sicurezza vieta a chiunque di eseguire delle chiamate se non si dispongono dei permessi adeguati.

Il workflow è il seguente:

- Lo smartphone si connette al servizio attraverso l’apposita App (Android e IOS)
- L’utente avrà un proprio username e password per accedervi
- Quando l’utente effettua delle richieste: aggiunte, modifiche ecc… disporrà di un certo token generato attraverso il processo di generazione di token di JWT, quindi ogni volta che un client accede avrà un token sempre diverso e nessun’altro potrà effettuare le sue richieste, ma solo lui e lui solo
- Una volta che il client esegue un’operazione, questa passerà prima dal backend, che controllerà se tale azione potrà essere eseguita e poi effettuerà le dovute manovre, come salvare i dati sul DB o modificarli
- Tutte le richieste che vengono effettuate hanno controlli in ogni parte del software, dal frontend al backend e perfino sul DB, attraverso dei trigger e controlli preliminari di accesso e gestione
- Una volta che la richiesta è stata effettuata verrà restituita l’azione specifica all’App, in modo da dare un messaggio visivo e chiaro all’utente che sta utilizzando l’applicazione

## TECNOLOGIE DEVICE

Le tecnologie utilizzate nella realizzazione del device e dell’app sono diverse:

- Bluetooth:
- La tecnologia Bluetooth è sicuramente la tecnologia più importate che viene utilizzata in questo progetto, in primis perché serve ad intercettare i contatti che avvengono con le persone ma anche per la comunicazione e il passaggio di dati attraverso lo smartphone.
- La tecnologia Bluetooth ha tante varianti e quella che si è utilizzata è chiamata BLE (Bluetooth low energy), cioè un Bluetooth con un basso utilizzo di energia.
- WiFi:
- La tecnologia WiFi viene utilizzata per permettere al device di connettersi, ad una rete domestica, che disponga di un WiFi, per poter inoltrare i dati al server con tutti i contatti avvenuti.
- La connessione al WiFi avviene attraverso uno scambio di informazioni con lo smartphone in cui l’utente dare al device le informazioni necessarie per connettersi ad una rete (SSID, PASS)
- La connessione al WiFi può avvenire anche in un altro modo, attraverso il metodo WPS, in cui l’utente, schiacciando il bottone con la sigla di quest’ultimo, può attivarlo sul proprio router di casa.

## RACCOLTA DATI (Questionario)

Durante la fase progettuale e durante i vari test, per verificare le varie tecnologie da utilizzare, si è somministrato un questionario, totalmente anonimo, attraverso diversi canali comunicativi, per sapere cosa ne pensava la gente su un particolare device o App per gestire l’emergenza.

Questi sono i dati che si sono tirati fuori da 250 risposte:

- Per prima cosa è stato chiesto cosa ne pensava la gente se ci fosse stato un “qualcosa” che avrebbe potuto gestire e aiutarci contro l’emergenza COVID-19 accedendo ad alcuni dati sensibili di ogni singola persona; queste sono state le risposte:

il 36,1% ha dato la sua negazione a questa
domanda
più del 55% ha acconsentito a questo
il restante 9% (circa) si è astenuto oppure ha rivolto delle lamentele a questa richiesta.

già questo fa emergere un dato abbastanza significativo sul modo di pensare delle persone, anche se la maggior parte fosse d’accordo, ci sarebbe comunque una parte, una bella fetta di popolazione che non vuole acconsentire a tutto


questo e non far gestire i propri dati personali a discapito di tutto.
In totale possiamo dire che 56% ha detto sì e 44% ha detto no, e questo va contro l’utilizzo dell’App “Immuni” per poter essere efficace (>60%).
- A quelle persone che hanno risposto di no, è stato chiesto il perché di questa risposta. Le risposte sono state delle più svariate, ma comunque rimane il non consenso da parte di quasi metà dei test.
- La successiva domanda è stata rivolta a tutti (sia si che no) e riguarda un argomento molto sentito negli ultimi tempi:
- Pensi che nei tempi in cui viviamo siamo costantemente "spiati"?


Qui quasi l’80% delle persone ha confermato la domanda. Quindi anche quelli che avevano risposo si all’utilizzo di alcuni dati sensibili sa che, comunque sia, viviamo in un modo dove siamo perennemente spiati.

- Le domande che arrivano subito dopo, parlano di social e di utilizzo di quest’ultimi. La serie di domande viene proposta per arrivare a quella più fantomatica, la seguente:
- Se ci dovesse essere una App o un dispositivo in grado di fronteggiare ogni virus possibile, ma che userebbe i tuoi dati personali, lo useresti?

Qui la risposta della maggior parte delle persone è positiva, un po' in contrasto con la primissima domanda. Quindi, le persone, una volta messe in un contesto in cui viene fatto capire che forse la App è l’ultimo dei nostri problemi di privacy, ha cambiato la propria idea, trasformandola in positiva. Questo fa ben sperare sui futuri sviluppi del device o di una qualche APP.

- Un’altra delle domande che è stata chiesta è abbastanza interessante, perché è riferita solamente a quelle persone che hanno risposto in modo negativo alla precedente:
- Se il dispositivo utilizza i dati in modo trasparente e chiaro all'utente finale, saresti d'accordo?


L’80% delle persone che ha risposto in modo negativo alla domanda precedente ha fatto marcia indietro ed ha deciso di adottare la soluzione, anche se questa utilizza una parte di dati sensibili.

- La domanda successiva chiede, più nello specifico, come i dati della persona venissero trattati:
- Vorresti che al dispositivo fosse associata anche una app per lo smartphone in grado di monitorare tutte le informazioni che sono state raccolte, in modo che tutte queste informazioni siano gestite attraverso un meccanismo del tutto chiaro e trasparente?


Quasi in totalità, le persone hanno dato una risposta positiva. Quindi si al device (o APP) ma che si gestisca al meglio i dati sensibili e che il tutto avvenga in modo trasparente per ogni individuo.

Quello raccolto da questo questionario è stato il nostro punto di partenza della struttura, la gestione e la utilizzabilità del device, della APP e di tutti i dati che dovranno essere gestiti e controllati in modo sicuro e trasparente all’individuo.

## CONCLUSIONI

Nell’ultimo periodo sono tante le applicazioni e i device che sono stati proposti per fronteggiare l’emergenza “coronavirus”, parecchie delle quali utilizzano solamente un’analisi dei dati, partendo da dati già raccolti, ma non sempre accurati, altre utilizzano smartphone attraverso la geolocalizzazione, ma inefficienti in ambienti chiusi o schermati.

Alcune software house hanno proposto delle App per smartphone in grado di raccogliere i dati con la tecnologia Bluetooth, ma, per il momento, sono poche le notizie che specificano in che modo verranno raccolti i dati e se ci saranno delle limitazioni a livello di sistema operativo.

Dal nostro punto di vita, quando si è iniziato a muove i primi passi nel progetto, si è pensato di utilizzare una semplice app smartphone, in modo che quest’ultima potesse essere facilmente realizzabile, con un costo irrisorio e con una distribuzione molto più elevata, ma si sono verificate diverse problematiche dovute alla struttura stessa dei sistemi operativi smartphone.

- La prima problematica la si è riscontrata su IOS, che mette a disposizione un servizio Bluetooth che filtra ed elimina tutti device Bluetooth non certificati MFI;
- La seconda problematica riscontrata (sempre su IOS) si è avuta sulla ricerca dei dispositivi Bluetooth in zona, infatti non riuscivamo a vedere il MAC Address dei device ma solamente l’UUID e questo ci ha creato delle problematiche alla realizzazione dell’idea e all’implementazione stessa del codice di sviluppo (UUID cambia sempre e spesso e non è un ID da poter considerare per identificare in modo univoco un device);
- La terza problematica, questa volta, è arrivata da Android, infatti, potevamo visualizzare tutti i dispositivi Bluetooth con i loro MAC Address, ma non riuscivamo ad accedere al nostro MAC privato per motivi di sicurezza imposti da Android (avevamo bisogno di conoscere il nostro MAC per utilizzarlo come ID ed essere identificato in modo univoco, nel sistema, come “persona in possesso di un device BubbleBox”).

Tuttavia, si sono riscontrate anche altre problematiche nell’utilizzo dello smartphone:

- Una problematica, non di poco conto, era sicuramente data dal consumo eccessivo di batteria provocava dallo scanning continuo del Bluetooth;
- Un’altra è il non possesso di alcun tipo di smartphone o il possesso di telefoni datati non adatti al compito:
- Anziani, bambini, senzatetto, persone che non ne vogliono uno…
- Problematica dovuta alla poca, o scarsa, consapevolezza nell’utilizzo di determinate tecnologie:
- Accensione del Bluetooth, avvio dell’App, controllo applicazione…
- E per finire il sovraccarico del server alle continue richieste che avrebbe ricevuto dall’applicazione.

Prima di arrivare a queste conclusioni, grazie ai test effettuati, la nostra idea, in principio, era strutturata in questo modo:

- Ogni smartphone faceva parte del sistema BubbleBox attraverso un’iscrizione all’app (tramite mail e password);
- Ogni smartphone era identificato in modo univoco attraverso il MAC Address (unico per ogni device);
- Quando si accedeva all’app, automaticamente si accendeva il Bluetooth e partiva la scansione periodica dell’area alla ricerca di altri device Bluetooth;

- I device, appartenenti alle persone, dovevano essere identificati rispetto agli altri milioni di device che sono in giro (cuffiette, Smart band, smartwatch e altro) e questo ha creato un altro problema non di poco conto che poteva essere gestito in questo modo:
- Ogni volta che si trovava in zona un Bluetooth ad una certa distanza (considerando l’RSSI che misura la potenza del segnale) lo si considerava e partiva una POST al server per poter aggiungere tale contatto in una tabella dei “contatti avvenuti” (chiamata blast per via dell’onomatopea impura dello scoppio della bolla);
- Questo identificativo (MAC Address) incontrato, veniva confrontato, lato server, con la tabella dei device presenti nel sistema, per vedere se tale ID appartenga ad una persona inserita nel sistema;
- Se il riscontro fosse stato positivo, si sarebbe aggiunto il contatto all’interno della tabella del DB, altrimenti tale ID del device veniva inserito, in locale, sullo smartphone della persona da cui è partita la segnalazione, in modo che ogni volta che avrebbe incontrato quel device avrebbe saputo già a prescindere che apparteneva ad un dispositivo che non faceva parte del sistema e quindi avrebbe evitato controlli inutili al server.

In questo workflow e nelle problematiche esposte in precedenza ci hanno fatto rivalutare l’uso dello smartphone. Infatti, si è pensato di passare il tutto ad una gestione più semplice, efficiente e facilmente indossabile da chiunque senza obbligo di smartphone: un device dalle sembianze di un orologio da polso (smartwatch).

La nostra soluzione di device copre tutte le pecche e le imperfezioni di altre applicazioni, idee e problematiche esposte in precedenza, in modo tale da avere sempre una raccolta precisa dei dati in ogni luogo e modo, al fine di poter essere utilizzati e analizzati.

Come tutte le considerazioni fatte, anche il device ai suoi pro e contro, che verranno descritti di seguito:

- PRO:
- Leggero e maneggevole
- Poco costoso
- Implementazione agevole
- Batteria dedicata
- Bassi consumi
- Indossabile da chiunque
- CONTRO:
- Tempi di realizzazione corposi
- Tempi di distribuzione lunghi ed onerosi

Sicuramente nella creazione del device abbiamo molti aspetti piacevoli ma anche alcuni negativi che bisogna tenere conto. Sicuramente una App ha una velocità di distribuzione elevata perché un software riesce a girare molto più velocemente e coprire molte più persone a livello locale, nazionale e mondiale. Tuttavia, anche la realizzazione tramite App ha delle pecche molto forti, alcune delle quali ampiamente discusse precedentemente, infatti, alcune software house che si stanno occupando di creare un’apposita applicazione per gestire l’emergenza, in questo momento (fine Aprile 2020), stanno pensando di utilizzare un device per coprire una parte della popolazione italiana, perché la App ha senso di esistere se almeno il 60% (e poco più) della popolazione la usa in modo impeccabile e in ogni momento. Ritornando al dato di prima, ricordiamo che l’Italia è il paese più longevo d’Europa (forse del mondo) con ben più del 22% della popolazione over 70. Questo dato è abbastanza chiaro se si pensa che buona parte di questa percentuale non possiede o non sa cosa sia uno smartphone. A questo c’è da aggiungere sicuramente una percentuale di almeno un 15% dei bambini, che non possiedono uno smartphone e a tutte quelle persone che non ne vogliono possedere uno. Anche se lo stato, imponesse per legge, che tutti devono tenere, obbligatoriamente, uno smartphone con uno strumento di tracciabilità continua (con grande consumo di batteria) sempre acceso, questo dovrebbe prevedere un acquisto forzato e obbligatorio di uno smartphone anche per i più neofiti.

Il nostro sistema copre questa parte della popolazione e tutto il resto, perché fornisce un device dove la tua unica preoccupazione sarà quella di metterlo in carica (una volta al giorno o ogni due giorni (forse) la sera) contro il fatto di avere un telefono sempre disponibile, acceso e con un consumo di batteria elevato.

Sicuramente nelle ultime settimane vedremo come si evolverà la situazione, la nostra idea rimane, tuttora, un’idea innovativa e valida che può essere utilizzata ed inglobata, insieme altre proposte presente in questo momento sul settore, ma anche in tantissimi altri ambiti.

## MANUALE D’USO

### 1. INIZIALIZZAZIONE DEVICE

Per poter inizializzare il device bisogna seguire i seguenti passi:

- Installare la IDE di Arduino sulla pagina ufficiale: https://www.arduino.cc/en/Main/Software


- Installare CORE ESP32 sulla IDE di Arduino:
- | Arduino IDE > File | > Impostazioni | > Schede | > URL Schede
> https://dl.espressif.com/dl/package_esp32_index.json
- | Arduino IDE > Strumenti | > Scheda | > ESP32 Dev Model
- | Arduino IDE > Strumenti | > Partition Scheme> NO OTA (2MB APP/2MB SPIFFS)
- Installazione librerie:
- Installazione librerie ESP32: https://github.com/espressif/arduino-esp32
- Installazione librerie RFNANO: https://github.com/maniacbug/RF24
- Possibili problematiche:
- è possibile che quando si connette l'ESP32 alla porta USB del PC non venga letta
- aprire Gestione Dispositivi
- vedere se tra i device presenti c'è qualche problema o warning

- andare sul problema e cliccare col tasto destro > Aggiorna Driver
- il problema dovrebbe essere rsolto riavviando la IDE di Arduino


2. FIRMWARE SCHEDE
- Clonare la repo
- git clone https://orteip94@bitbucket.org/bbteam_/bubblebox-device.git


- Installare gli sketch sulle schede:
- RFNANO:
- Aprire Arduino IDE
- Inserire la scheda RFNANO
- Arduino IDE > Strumenti > Scheda > Arduino Nano > Processore:ATMega328P
- Selezionare Porta
- Installare sketch contenuto nella directory Sketch Device/RFNano


- ESP32:
- Aprire Arduino IDE
- Inserire la scheda ESP32
- Arduino IDE > Strumenti > Scheda > ESP32 Dev Model
- Arduino IDE > Strumenti > Partition Scheme > NO OTA (2MB APP/2MB SPIFFS)
- Selezionare Porta
- Installare sketch contenuto nella directory Sketch Device/ESP32/Device_Sleep&Wake


3. APP

La schermata iniziale dell’app è molto semplice, infatti, verrà chiesto di entrarci, con le proprie credenziali, oppure registrarsi, se non si dispone di quest’ultime.

Nel campo “Username” verrà inserito il nome utente che si è creato in fase di registrazione, mentre la password sarà creata anch’essa in fase di registrazione.

Se si è dimenticati la password sarà possibile cliccare su “Forgot Password?” per recuperarla attraverso i vari metodi di recupero.


La schermata registrazione è la seguente:

La schermata presenta vari campi da compilare per potersi registrare ed entrare per gestire le varie opzioni e il device di cui si dispone

I campi sono i seguenti:

- Name:
a. Nome della persona che si vuole registare
- Surname:
a. Cognome della persona che si vuole registrare
- Fiscal Code:
a. Codice fiscale
- Birth Date:
a. Data di nascita
- Gender:
a. Sesso
- Username:
a. Nome utente con il quale accedere all’app per entrare nella propria area riservata
- Email:
a. Mail dove ricevere le varie notifiche e recupero password
- Password:
a. Password con cui si accederà al servizio


Schermata di home di accesso:

La schermata di home
presenta un menù in alto a sinistra che una volta cliccato ci aprirà una sequenza di
azioni da poter eseguire:
- Home: home app
- Device: inserimento e
gestione device

Le altre impostazioni sono riservate solo allo staff e admin per la gestione delle emergenze e segnalazioni.

Nella schermata home sarà
presente il numero dei
contatti giornalieri e quelli degli ultimi 14 giorni, ma non si potrà sapere con chi si è venuto a contatto (per
privacy).

Sarà presente un bottone
“Report Synptoms” in cui
sarà possibile effettuare una segnalazione dei propri
sintomi, qualora si pensi di essere infetti.

Saranno presente, in fondo alla schermata, delle buone regole da seguire e rispettare.

In alto a destra della schermata sarà presente lo stato di salute attuale.

Cliccando su “Device” presente nella home, potremo gestire il device:

Se non si è inserito alcun device sul proprio profilo, verrà richiesto di inserirne uno. Seguendo i vari passaggi visualizzeremo le seguenti schermate:


Verrà chiesto di scansionare il QRCode del dispositivo BubbleBox, in modo da inserirlo tra i propri dispositivi. Il QRCode sarà presente nella confezione del device e nel display andando nell’apposita sezione. Basta inquadrare tale codice e il device verrà inserito.


### 4. MOCKUP DISPLAY DEVICE

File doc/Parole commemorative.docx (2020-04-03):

Sistema di rilevamento di prossimità per prevenire e rilevare l’espansione del COVID-19, attraverso l’uso di un device (da realizzare) o smartphone (con una App attraverso l’ausilio di tecnologie Bluetooth).

Oltre all’analisi dei dati, questo progetto, effettua soprattutto una raccolta puntuale, completa e organizzata, con dati pronti per essere analizzati.

Il nome BubbleBox proviene proprio dall’idea di una bolla virtuale attorno ad ogni individuo che, se violata, da quella di un altro, ottiene ID di quest’ultimo e invia la segnalazione ad un server online per analisi e verifiche future.

Se un individuo dovesse essere positivo al COVID-19 allora verranno allertate e controllate tutte le persone con cui è entrato in contatto senza ambiguità alcuna.

A differenza di alcuni sistemi di tracciamento già presenti, il nostro fornisce un servizio funzionante in ogni luogo e offline, perché la raccolta avviene prima in locale poi, quando disponibile, viene inoltrata online.

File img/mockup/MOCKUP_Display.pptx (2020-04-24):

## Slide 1

BubbleBox

36°C

10:30
2020/12/12

Bottone 1

10
Persone Incontrate


Display di accensione

Bottone 2

Home

Bottone 2

Bottone 1

Connessione
Riuscita
Invio Dati…

Bottone 1

Attiva
WPS

Connessione WiFi
WPS

Ripeti

Bottone 2

Wi-Fi

Connessione
In corso…

Connessione WiFi
AP

Bottone 1

Bottone 2

Bottone 1

Router wireless

Bottone 1

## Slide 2

Connessione WiFi
AP

Connessione Smartphone

36°C

10:30
2020/12/12

Bottone 2

Bottone 1

Smartphone

Bottone 2

Bottone 1

Nome:
[BubbleBox_Device]

QR-CODE

QR Code Generator | Crea il tuo Codice QR Qui

Bottone 1

Bottone 1

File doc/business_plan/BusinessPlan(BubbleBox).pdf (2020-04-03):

| | | 2020 | 2021 | 2022 | 2023 | 2024
Costi di investimento | unità | prezzo | EUR | EUR | EUR | EUR | EUR
Macchine, rete, stampanti | | 10.000,00 € | 10.000,00 €
Costi di costituzione | | 5.000,00 € | 5.000,00 €
Totale | | | 15.000,00 €

Fonti di finanziamanto

Equity proprio | 5 | 3.000,00 € | 15.000,00 €
Finanziatori esterni (Aziende Sanitarie) | 60.000,00 € | 60.000,00 €
Con Finanziatori | 75.000,00 €
Senza Finanziatori | 15.000,00 €

Ricavi operativi

Customer base subscription | 30.000 | 20,00 € | 600.000,00 € 630.000,00 € 630.000,00 € 660.000,00 € 690.000,00 €
Dealer base subscription | 5.000 | 50,00 € | 250.000,00 € 262.500,00 € 275.000,00 € 287.500,00 € 300.000,00 €
Totale base | 35.00
0 70,00 €
| | | 850.000,00 € | 892.500,00 € | 905.000,00 € | 947.500,00 € | 990.000,00 €

Totale Ricavi Operativi

850.000,00
€

892.500,00
€

905.000,00
€

947.500,00
€

990.000,00
€

Costi Operativi

Spese per il personale (lordo) | 5 | 30.000,00 € | 150.000,00 € 150.000,00 € 150.000,00 € 150.000,00 € 150.000,00 €
Spese per servizi (affitto ufficio) | 1 | 6.000,00 € | 6.000,00 € | 6.000,00 € | 6.000,00 € | 6.000,00 € | 6.000,00 €
Manutenzione macchine | | | 500,00 € | 500,00 € | 500,00 € | 500,00 € | 500,00 €
Costi dispositivi e schede
elettroniche | 40.000 | 5,00
€ | 200.000,00 € 200.000,00 € 200.000,00 € 200.000,00 € 200.000,00 €
Costi elettronica generale | | | 5.000,00 € | 5.000,00 € | 5.000,00 € | 5.000,00 € | 5.000,00 €
Costi produzione device | 35.000 | 10,00
€ | 350.000,00 € 350.000,00 € 350.000,00 € 350.000,00 € 350.000,00 €
Costi distribuzione e logistica | | | 50.000,00 € | 50.000,00 € | 50.000,00 € | 50.000,00 € | 50.000,00 €
Manutenzione e sostituzione
device | 5.000 | 15,00
€ | 75.000,00 € | 75.000,00 € | 75.000,00 € | 75.000,00 € | 75.000,00 €
Costi di pubblicità | | | 20.000,00 € | 20.000,00 € | 20.000,00 € | 20.000,00 € | 20.000,00 €

Totale Costi Operativi

856.500,00
€

856.500,00
€

856.500,00
€

856.500,00
€

856.500,00
€
Capitale (Senza Finanziamenti) | 0,00 €
Capitale (Con Finanziamenti) | 60.000,00 €
Flussi di cassa (Senza
Finanziamenti) | -6.500,00 € | 36.000,00 € | 48.500,00 € | 91.000,00 € 133.500,00 €
Flussi di cassa (Con Finanziamenti) | 53.500,00 € | 36.000,00 € | 48.500,00 € | 91.000,00 € 133.500,00 €
Flussi di cassa cumulati (Senza
Finanzaimenti) | -6.500,00 € | 29.500,00 € | 78.000,00 € 169.000,00 € 302.500,00 €
Flussi di cassa cumulati (Con Finanzaimenti) | 53.500,00 € | 89.500,00 € 138.000,00 € 229.000,00 € 362.500,00 €

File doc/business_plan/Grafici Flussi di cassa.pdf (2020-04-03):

-50.000,00 €

0,00 €

50.000,00 €

100.000,00 €

150.000,00 €

200.000,00 €

250.000,00 €

300.000,00 €

350.000,00 €

1 | 2 | 3 | 4 | 5

## FLUSSO DI CASSA CUMULATI (SENZA FINANZE)

0,00 €

50.000,00 €

100.000,00 €

150.000,00 €

200.000,00 €

250.000,00 €

300.000,00 €

350.000,00 €

400.000,00 €

1 | 2 | 3 | 4 | 5

## FLUSSO DI CASSA CUMULATI (CON FINANZE)

-100.000,00 €

Serie1; Serie2

0,00 €

100.000,00 €

200.000,00 €

300.000,00 €

400.000,00 €

500.000,00 €

600.000,00 €

700.000,00 €

## Flussi di cassa a confronto

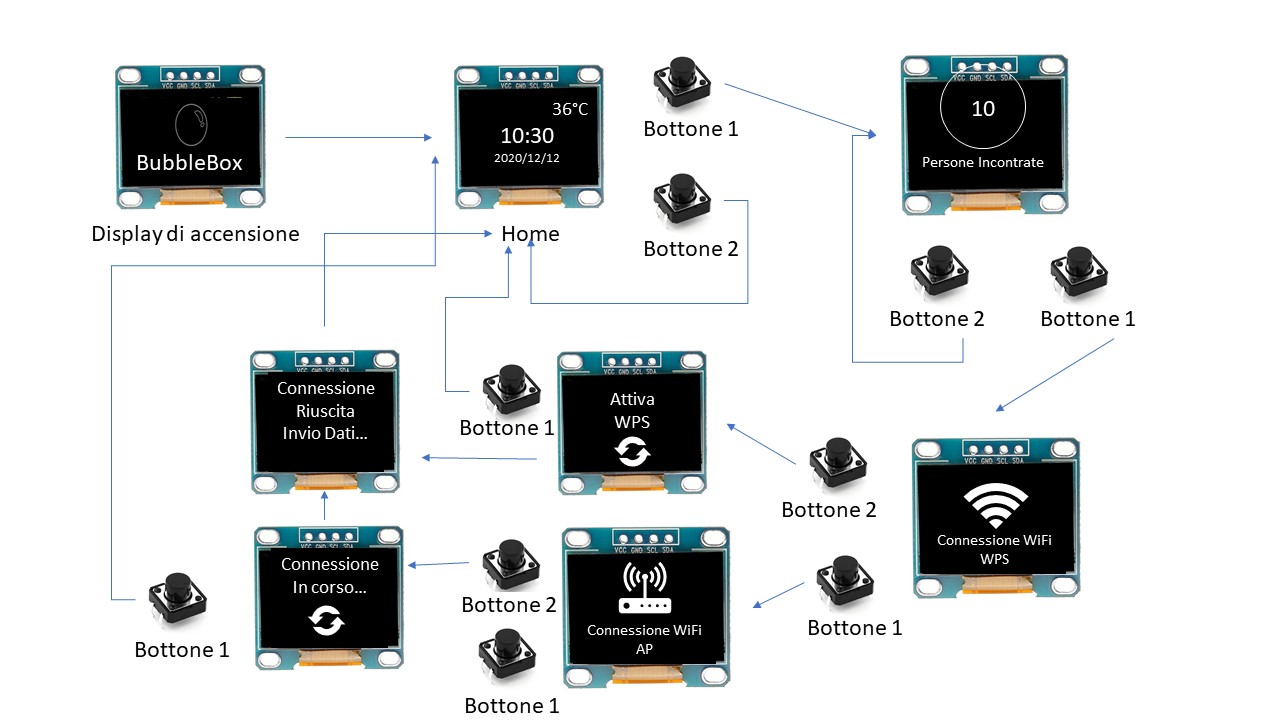
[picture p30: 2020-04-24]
img/mockup/Diapositiva1.JPG

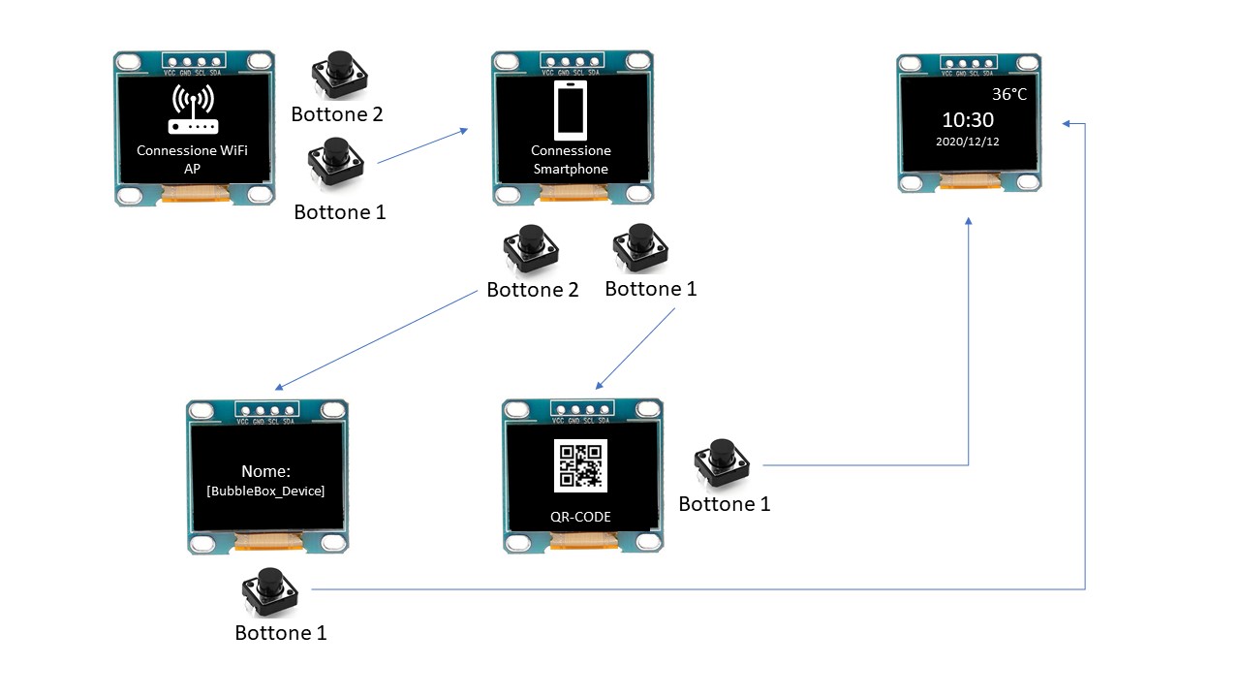
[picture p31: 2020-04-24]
img/mockup/Diapositiva2.JPG

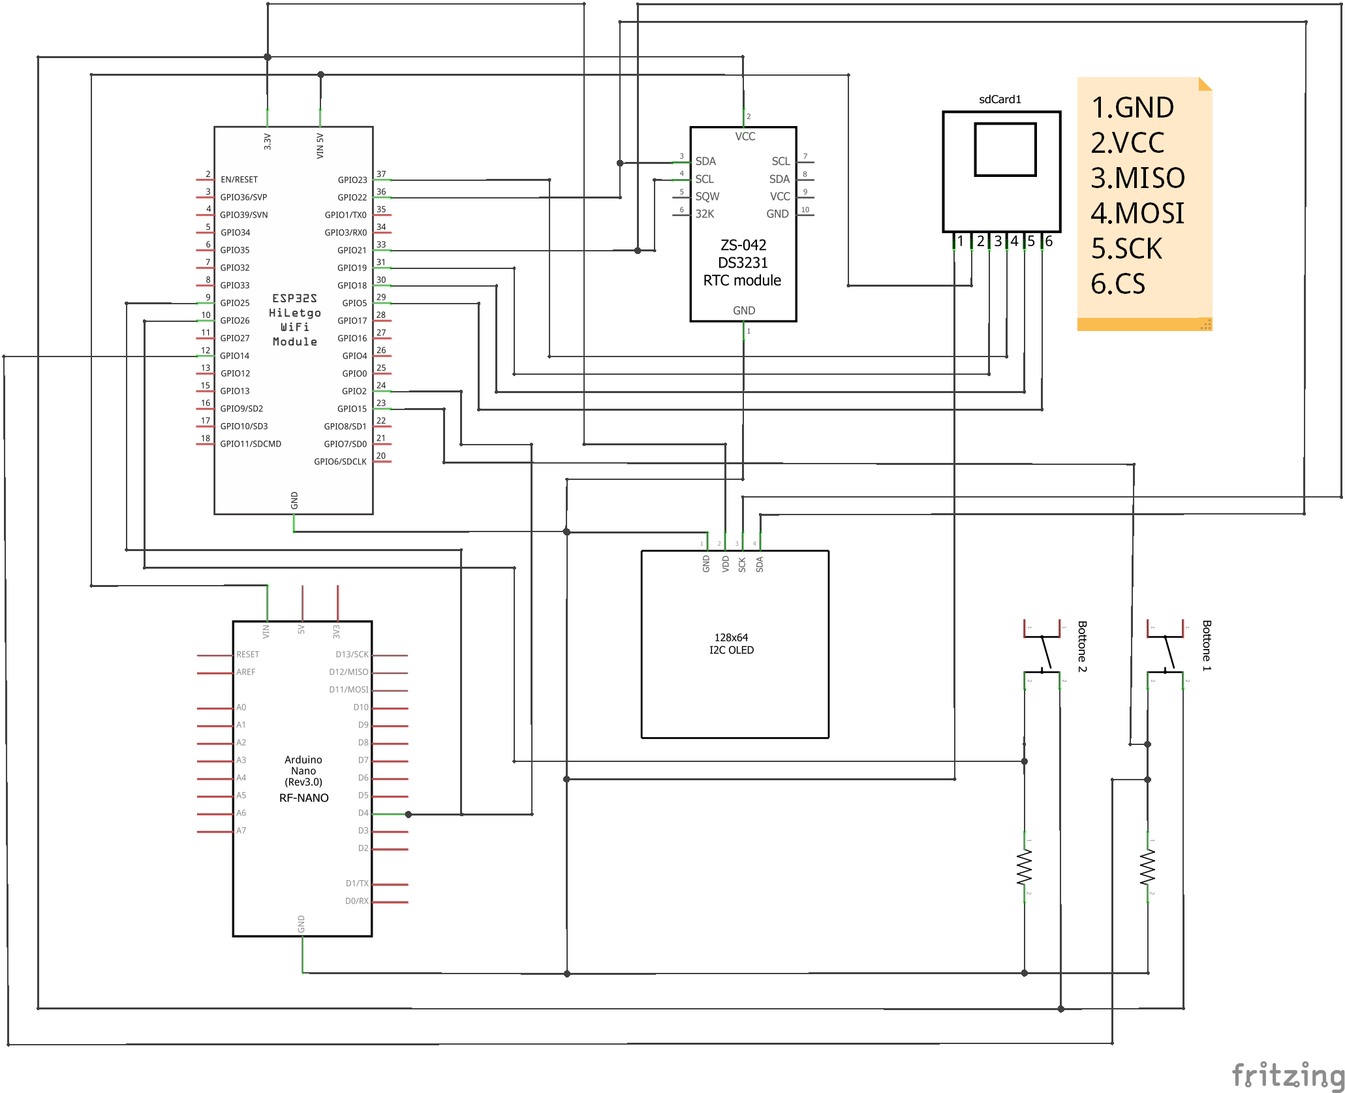
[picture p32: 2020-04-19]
circuits/Circuito_Dettagliato.png

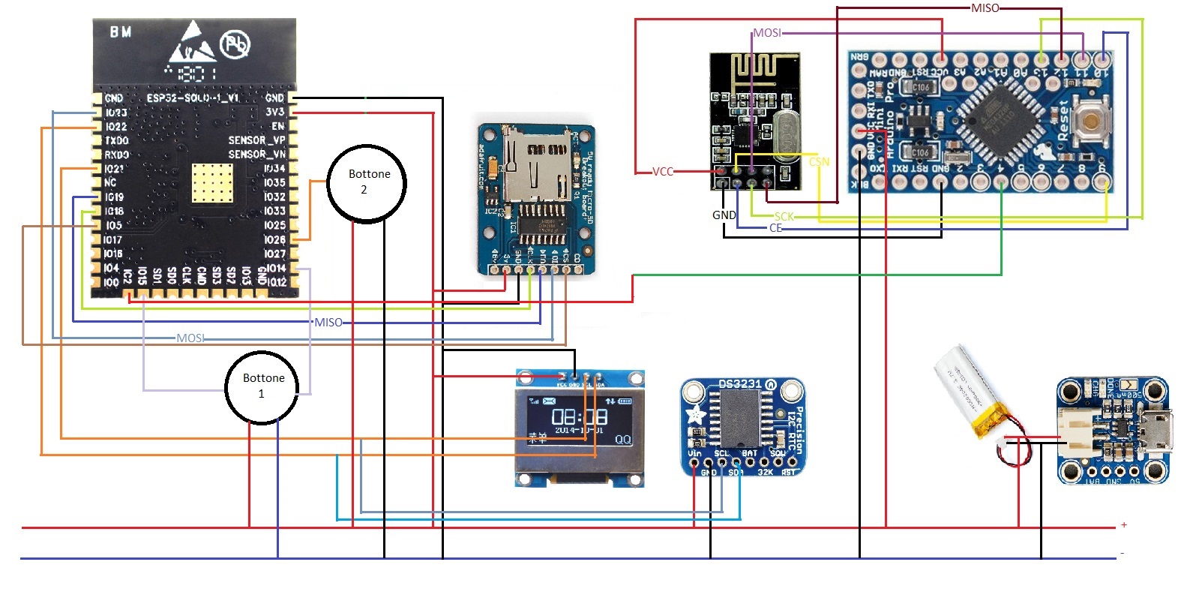
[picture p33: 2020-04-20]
circuits/Circuito_Semplice_Ridotto.jpg

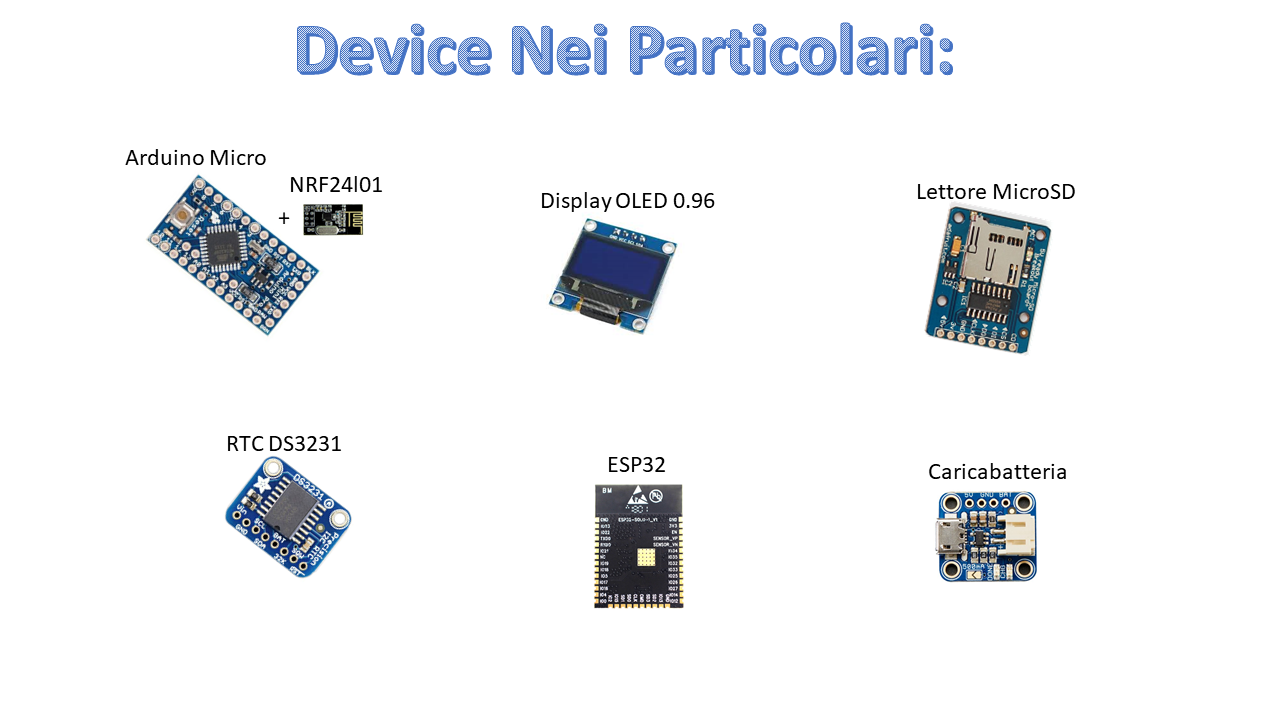
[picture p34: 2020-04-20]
scheme/Device_Parti.PNG

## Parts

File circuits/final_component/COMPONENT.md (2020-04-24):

- [SD CARD](https://www.adafruit.com/product/254)

- [ESP32 CHIP](https://www.amazon.it/ESPRESSIF-pezzi-Modulo-ESP-WROOM-32-ESP32/dp/B07DB9YP7Q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)

- [RTC DS3231](https://www.adafruit.com/product/3013)

- [Display OLED 0.96](https://www.amazon.it/AZDelivery-Display-retroilluminato-Raspberry-gratuito/dp/B078J78R45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)

- [Arduino PRO MINI](https://www.amazon.it/IZOKEE-Enhancement-ATMEGA328P-ATmega128-Microcontrollore/dp/B078HM2LC3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)

- [NRF24L01](https://www.amazon.it/AZDelivery-NRF24L01-Wireless-Arduino-Raspberry/dp/B06XJN417D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)

- [RECHARGABLE BATTERY](https://www.adafruit.com/product/4410)

- [BATTERY](https://www.amazon.it/Batteria-ricaricabile-litio-DZ09-capacit%C3%A0/dp/B07FMKSNSC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)

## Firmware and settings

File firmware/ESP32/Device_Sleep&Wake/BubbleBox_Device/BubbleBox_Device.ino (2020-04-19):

/*
 * BubbleBox vers. 1.0 Pietro Rignanese & Andrea Polenta 2020
 * 
 * Contatti: 
 *  - pietro_rignanese@hotmail.it
 *  - andrea.polenta@outlook.it
 * 
 * #####################################---BUBBLEBOX---################################################
 * 
 * UNIVPM --> Progetto di Sistemi Operativi Distribuiti e Tempo Continuo 
 * 
 * Prof: Aldo Franco Dragoni
 * 
 */
 
//--- Nome, MAC Address, Rssi e Manifattura del dispositivo trovato -----------
String MAC;
String Name;
String Manufacturer;
int Rssi_device = 0;
String UUID;
//------------------------------------------------------------------------------

//--- MAC Address BLE di questo dispositivo-------------------------------------
String MyMAC;                         // Mio MAC Address BLE device ESP32

//---Variabile sul ritrovamento di altri device BUBBLEBOX-----------------------
bool BubbleBoxTrovato = false;        // Ritrovamento Device BubbleBox in zona

//---------- Caratteristiche Sleep&Wake-----------------------------------------
RTC_DATA_ATTR int bootCount = 0;      // Conteggio boot device
int ControlTimeWake = 0;              // Controllo tempo di Wake
const int RF_Nano = 25;               // Segnale di Controllo "RITROVAMENTO" device in zona --> Tiene accceso il BLE se si accorge della presenza di altri BUBBLEBOX

//------- Caratteristiche Display OLED 0.96"------------------------------------
const int statoDisplay = 14;          // Bottone per cambiare il display --> 4 tipologie di display
int numeroDisplay = 0;                // Numero del display corrispondente

//------- Caratteristiche Connessione BLT Seriale ------------------------------------
const int selFunction = 26;           // Bottone per la selezione della funzione display
bool statoBLT = false;                // Bluetooth seriale attivato/disattivato
bool bubbleStation = false;           // BubbleStation rilevata --> La bubbleStatio è ho un normale AP (router WIFI) o un device dato in dotazione con il device BUBBLEBOX
bool smartphoneConnect = false;       // Connessione Bluetooth Serial tramite smartphone attivata/disattivata
bool openConnBLT = false;             // Apertura connessione serial bluetooth

//------- Librerie realizzate "AD HOC" per la gestione dell'intero programma---------------------------------
#include "Display_IconeDisplay.h"     // Libreria per la gestione delle icone del display 
#include "Display_GestioneDisplay.h"  // Libreria per la gestione del sisplay
#include "SD_GestioneSDCard.h"        // Libreria per la gestione dell'SD Card
#include "ESP32_BLEDevice.h"          // Libreria per il device Bluetooth ESP32
#include "ESP32_SleepWake.h"          // Libreria per lo Sleep&Wake ESP32
#include "ESP32_SerialBLT.h"          // Libreria per la connessione Bluetooth Seriale
#include "RTC_Clock.h"                // Libreria per ora e data
#include "ESP32_WiFi.h"               // Libreria per la connessione WiFi
#include "SelectFunction_Button.h"    // Libreria per la selezione della funzione display tramite bottone


//------------------------- SETUP ----------------------------------------------------
void setup() 
{  
  BubbleBoxTrovato = false;         // setto la variabile del ritrovamento dispositivo a false

  // ------------ Settaggio bottone Interrupt per cambiare il display ---------------------
  pinMode(statoDisplay, INPUT_PULLUP);
  attachInterrupt(statoDisplay, controlloCambioDisplay, RISING);
  display.init();
  display.flipScreenVertically();
  //---------------------------------------------------------------------------------------

  // ------------ Settaggio bottone Interrupt per cambiare il display sulla connessione BLT e WPS ---------------------
  pinMode(selFunction, INPUT_PULLUP);
  attachInterrupt(selFunction, selectFunction, RISING);
  //---------------------------------------------------------------------------------------

  //------------ Settaggio INPUT proveniente dall'RFNano per i dispositivi nei dintorni----
  pinMode(RF_Nano, INPUT);
  ControlTimeWake = 0;              // Time clock del programma (per tenere acceso lo schermo) settato a zero(0)
  
  Serial.begin(115200);             // Inizializzazione monitor seriale per il debug

  setSDCard(getDataFile());         // Setto l'SD card --> SD_GestioneSDCard.h
  
  enableBLE();                      // Abilitare il Bluetooth Low Energy --> ESP32_BLEDevice.h
}

//-------------------------- LOOP ----------------------------------------------------------
void loop() 
{
  //---------- Controllo stato connessione Bluetooth Seriale, per connettere smartphone o WIFI --> Disabilito tutto il resto del device 
  if(statoBLT)
  {
    accendiDisplay("", "", "", "");                                                 // Accensione schermo --> Display_GestioneDisplay.h --> passo come parametri delle stringhe vuote perchè nella schermata che sto per aprire non ho bisogno di fìdata, ora e altre info
    if(smartphoneConnect)                                                           // Controllo se sta avvenendo una connessione ad uno smartphone
    {
      // ------ Connessione e invio dati allo smartphone
      sendDataSmartphone();                                                         // --> ESP32_SerialBLT.h
    }
    else
    {
      if(bubbleStation)                                                             // Controllo se ci si vuole connettere alla Station o ad un WIFI tramite WPS
      {
        connectStation();                                                           // Connessione STATION -_> ESP32_WPS.h
      }
      else
      {
        //---- Ci si vuole connettere ad una rete WIFI tramite WPS
        connectWPS();                                                               // Connessione WPS --> ESP32_WPS.h
      }
    }
  }
  else
  {     
    ++ControlTimeWake;                                                              // Tempo di accensione del display va avanti di +1 ad ogni inizio loop
  
    accendiDisplay(getData(), getOra(), getTemp(), countContatti(getDataFile()));   // ACCENDO IL DISPLAY --> Viene accesa la schermata in base al numero di tocchi del bottone --> Display_GestioneDisplay.h
    
    scanArea(getOra(), getDataFile());                                              // Scansione area per trovare i device con BLE nelle vicinanze --> scanArea() --> ESP32_BLEDevice.h
    
    disconnectedDeviceBLE();                                                        // Disconnesione dei dispositivi che si connettono --> Mantenere il device BLE esp32 sempre disponibile alla ricerca da parte di tutti gli altri device
  
    // Controllo per accendere o tener acceso il device in base a quanto tempo rimane in attesa o se non riceve nessun segnale dall'RFNANO
    // Controllo tempo di accensione e RF-NANO non trova device nei dintorni
    // Controllo se è stato tentato un pairing con uno smartphone tramite bluetooth
    //  qualora fosse avvenuto, e avviene una disconnessione o un cambio schermo, spengo lo schermo
    //  perchè ci sono dei problemi sulla scheda a ritornare al normale funzionamento dopo aver spento la connessione bluetooth serial
    //  ----> Se spengo il device e poi lo riavvio questo problema è bypassato!
    if((ControlTimeWake == 15 && digitalRead(RF_Nano) == LOW) || openConnBLT)
    {
      openConnBLT = false;                                                          // Riporto la variabile di connessione BLT serial a false per ripristinare il servizio qualora si fosse tentato di connettersi tramite smartphone
      spegniDisplay();                                                              // --> Display_GestioneDisplay.h
      setSleepWake();                                                               // --> ESP32_Sleep&Wake.h
    }
    else
    {
      // Il tempo va avanti ma l'RF-NANO continua a trovare dispositivi nelle vicinanze
      if(digitalRead(RF_Nano) == HIGH)
      {
        ControlTimeWake = 0;                                                        // Riporto a zero il contatore
      }
    }
  }
}

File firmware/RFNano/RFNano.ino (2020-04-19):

/*
 * --------------------------BUBBLEBOX ver. 1.0--------------------------------------
 * 
 * Device RF-NANO
 * 
 * Pietro Rignanese & Andrea Polenta 2020
 * 
 * UNIVPM
 * 
 * prof: Aldo Franco Dragoni
 * 
 */

//-------------- Librerie per la gestione del modulo wirless
#include <SPI.h>
#include "RF24.h"

//-------------- Librerie per lo sleep&wake
#include "LowPower.h"

const int AccensioneBubbleBox = 4;                    // Segnale di accensione dell'ESP32


RF24 radio(10, 9);                                    //CE - CSN --> Settaggio modulo radio
const uint64_t pipe = 0xE8E8F0F0E1LL;

//----------STRUTTURA DATI DA MANDARE E RICEVERE---------------
struct package 
{
  char id[20] = "BUBBLEBOX_DEVICE";                   // Nome Device
  unsigned long timeStamp;                            // Tempo di esecuzione del device
};

//------- Strutture dati da ricevere e mandare ---------------
typedef struct package Package;
Package dataRicev;
Package dataTransmit;
//--------------------------------------------------------------

int clockTime;                                       // Tempo di accensione del device

void setup() {
  clockTime = 0;                                     // Inizializzazione tempo accensione device a zero
  
  pinMode(AccensioneBubbleBox, OUTPUT);
  
  Serial.begin(115200);
  delay(1000);
//-------------------------------------------------- Inizializzazione Radio ---------------------------
  radio.begin();
  radio.setChannel(115);
  radio.setPALevel(RF24_PA_MIN);
  radio.setDataRate(RF24_250KBPS);
  radio.openReadingPipe(1, pipe);
  radio.startListening();
  radio.powerDown();
}
//--------------------------------------------------------------------------------------------------------

void loop() 
{
  ++clockTime;                                        // Il tempo di veglia si incrementa
  sleepWake();                                        // Funzione Sleep&Wake
  
  ricezione();                                        // Controllo se è arrivato qualcosa in ricezione
  delay(500);
  radio.stopListening();
  trasmissione();                                     // Trasmetto informazioni
}

//--------------RICEZIONE MESSAGGI------------------------
void ricezione()
{
  if(radio.available()) {
    while (radio.available()){
      radio.read(&dataRicev, sizeof(dataRicev));
    }
    if (strcmp (dataRicev.id,"BUBBLEBOX_DEVICE") == 0)
    {
      Serial.println("BUBBLE BOX TROVATO!");
      digitalWrite(AccensioneBubbleBox, HIGH);
      clockTime = 0;
    }
    Serial.println("________________RICEZIONE__________________ ");
    Serial.println("Package: ");
    Serial.print("ID:");
    Serial.print(dataRicev.id);
    Serial.print("\nYour/My Time:");
    Serial.print(dataRicev.timeStamp);
    Serial.println("\n------------------------------");
  }
}

//--------------TRASMISSIONE MESSAGGI-------------------------
void trasmissione()
{
  unsigned long now = millis();
  dataTransmit.timeStamp = now;
  digitalWrite(AccensioneBubbleBox, LOW);
  Serial.println("\n\n________________TRASMISSIONE___________________");
  Serial.println("Package: ");
  Serial.print("ID:");
  Serial.print(dataTransmit.id);
  Serial.print("\nMy Time:");
  Serial.print(dataTransmit.timeStamp);
  Serial.println("\n--------------------------------");

  radio.openWritingPipe(pipe);
  radio.write(&dataTransmit, sizeof(dataTransmit));
  radio.openReadingPipe(1, pipe);
  radio.startListening();
}

//--------------------SLEEP & WAKE  MODULO----------------------
void sleepWake()
{
  // Quando il modulo non ha trovato alcun dispositivo nelle vicinanze, si spegne per 4 secondi e poi riparte
  // Appena trova un device nelle vicinanze comincia a trasmettere senza mai fermarsi e tiene acceso l'ESP32
  if (clockTime > 15)
  {
    clockTime = clockTime - 1;
    LowPower.powerDown(SLEEP_4S, ADC_OFF, BOD_OFF); 
  }
}

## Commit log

2020-04-03 Insert business plan e presentation
    [BusinessPlan(BubbleBox).xlsx]
2020-04-03 Insert logo
2020-04-03 Device RFNano
2020-04-03 Device ESP32(Sempre attivo)
2020-04-03 Device ESP32(Sleep&Wake)
2020-04-03 Add Library BLE ESP32
2020-04-03 init display device
2020-04-05 move README deviced
2020-04-09 Bug Fix and getName device OK!
    [01_Device.ino]
2020-04-10 Add temperatura display
2020-04-10 add image circuit
2020-04-11 add img circuit complete!
2020-04-15 WPS connection Bug Fix
    [BubbleBox_Device.ino]
2020-04-16 Add circuits image
    [Circuito_Dettagliato.fzz, Circuito_Semplice.fzz]
2020-04-17 Set Data Time RTC when ESP32 connect WIFI
2020-04-19 Bug Fix RF NANO
    [RFNano.ino]
2020-04-19 Modify Image Circuits
    [Circuito_Dettagliato.fzz, Circuito_Semplice.fzz]
2020-04-19 Bug FIX conn BLT Serial OK
    [BubbleBox_Device.ino]
2020-04-20 Modifica schema e immagini device e funzionamento
2020-04-20 Add image schema e circuit function
2020-04-24 add doc and scheme
    [BusinessPlan(BubbleBox).xlsx, Circuito_Dettagliato.fzz, Circuito_Semplice.fzz]
